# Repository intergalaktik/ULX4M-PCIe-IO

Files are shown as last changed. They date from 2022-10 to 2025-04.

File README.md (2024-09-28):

# ULX4M-PCIe-IO
NLnet funded PCIe board that can hold ULX4M-LD 

## PCIexpress-KiCad templates
PCI Express™ libraries and templates for KiCad
Made using guidelines from PCI Express™ Card Electromechanical Specification Rev. 1.1

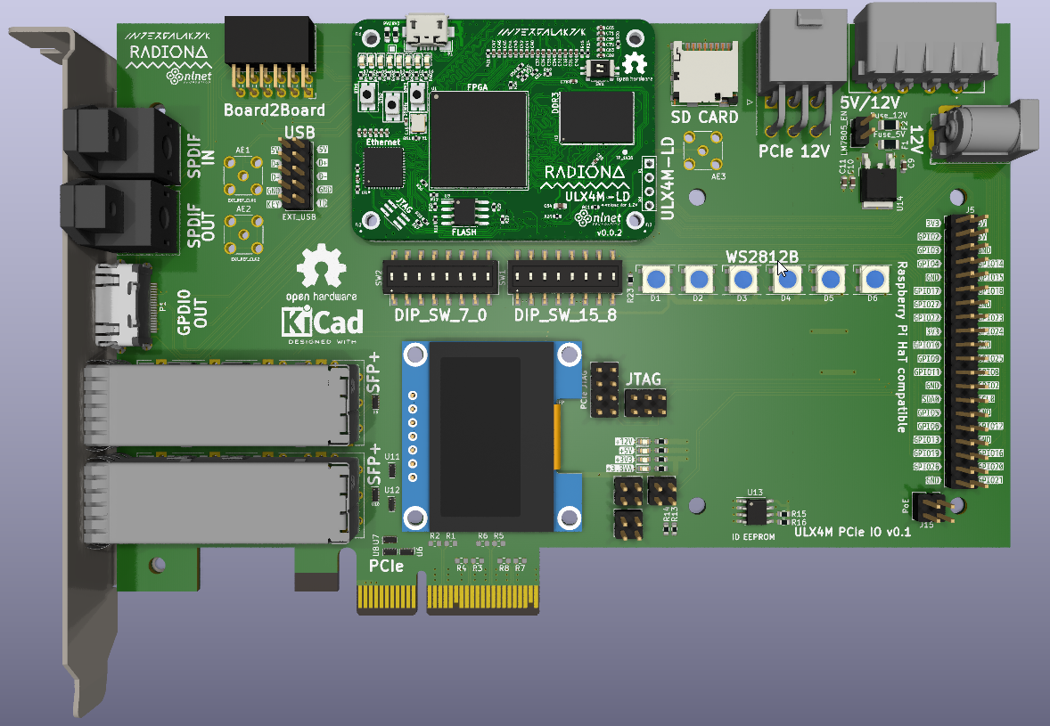
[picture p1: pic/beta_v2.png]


### Contents
**Template used:**
* x4 cards: full size, half length, low profile

**FPGA reference boards:**

* https://github.com/gatecat/TrellisBoard
* https://github.com/enjoy-digital/litex-acorn-baseboard

**Symbols:**
* x4
* Bracket

**Footprints:**
* x4 with multiple card outlines
* Full height bracket (with 3D model)

## Comfirmed working

- [x] 12V
- [x] 5V
- [x] 3.3V
- [x] DVI
- [x] WS2812 diodes
- [x] FTDI ove HAT

## Partially working

- [ ] PCIe loopback is working if TX/RX is bricked on boad edge, but not with PCIe externsion on CM4 IO board

## Not tested

- [ ] GPIOs
- [ ] SPDIFs
- [ ] SFPs
- [ ] PCIe comm to PC

# Not working

- [ ] OLED - pins are not connected on ULX4M
- [ ] 1x / 4x PCIe selection - it is not connected

### License
This documentation describes Open Hardware and is licensed under the CERN OHL v.1.2.

You may redistribute and modify this documentation under the terms of the CERN OHL v.1.2. (http://ohwr.org/cernohl). This documentation is distributed WITHOUT ANY EXPRESS OR IMPLIED WARRANTY, INCLUDING OF MERCHANTABILITY, SATISFACTORY QUALITY AND FITNESS FOR A PARTICULAR PURPOSE. Please see the CERN OHL v.1.2 for applicable conditions.

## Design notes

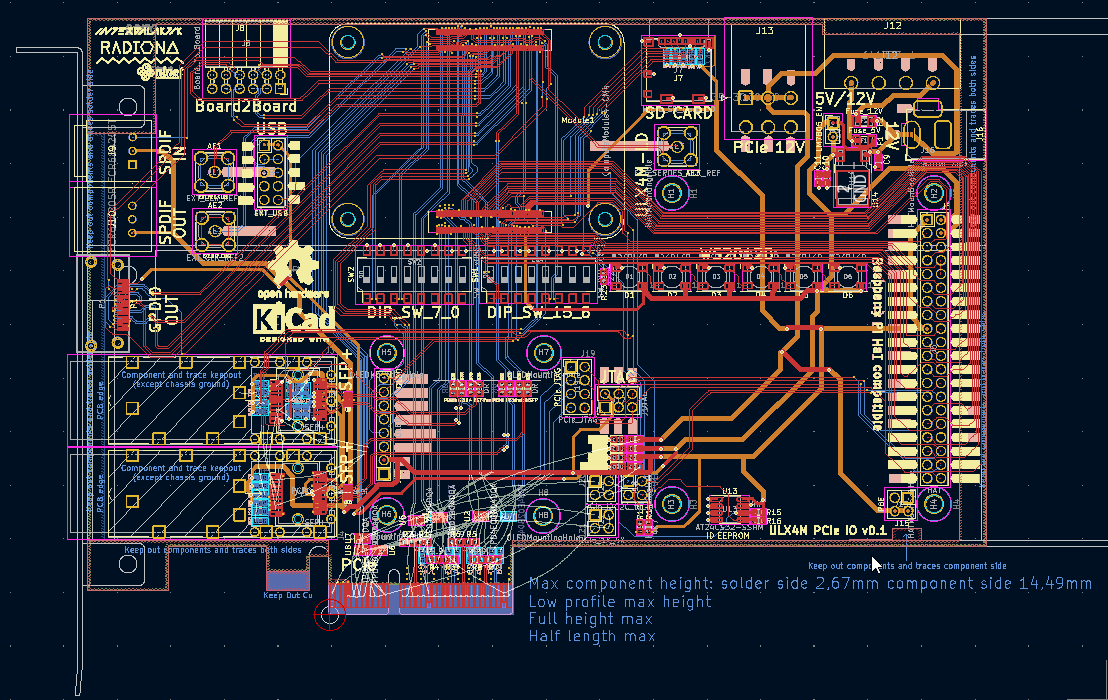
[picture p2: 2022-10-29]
pic/routing_status.png

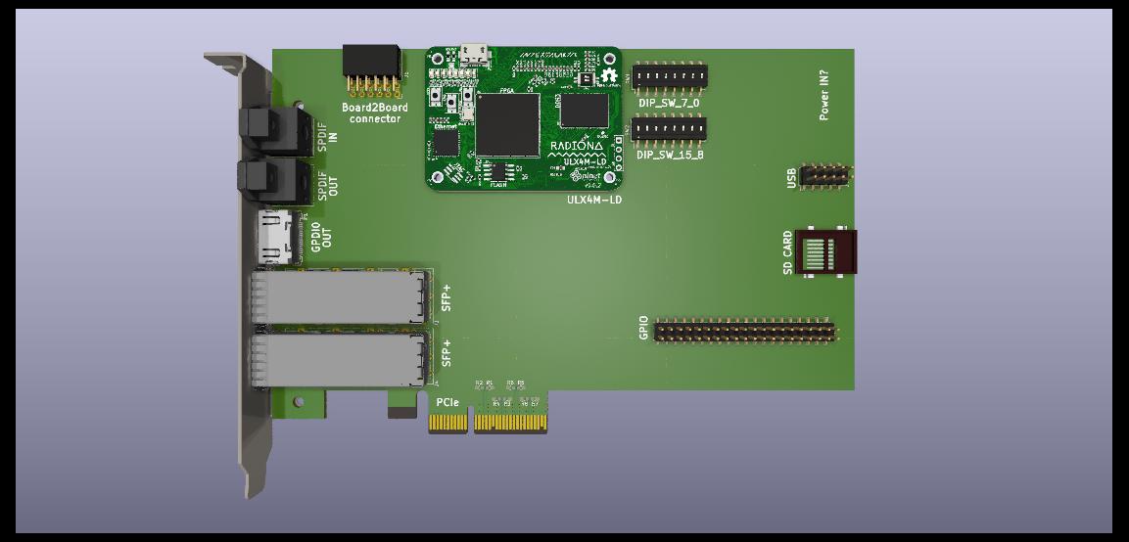
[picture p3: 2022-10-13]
pic/example.jpg

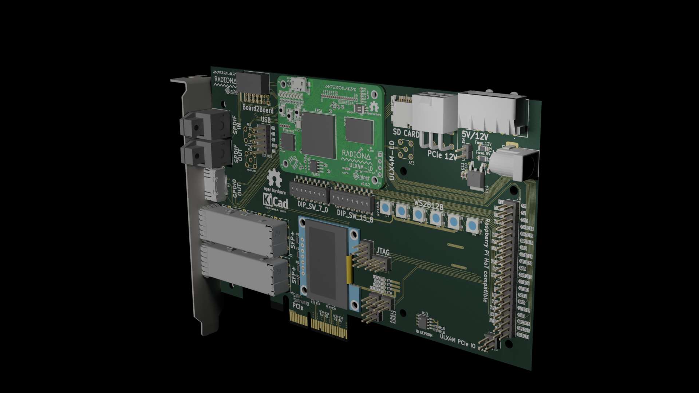
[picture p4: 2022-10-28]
3D/ULX4M-PCIE-IO.png

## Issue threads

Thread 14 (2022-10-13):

Adding few buttons

goran-mahovlic, 2022-10-13:

goran-mahovlic, 2022-10-24:
We have buttons on ULX4M, also all current pins are. When inside case buttons are useless...

Closed 2022-10-24.

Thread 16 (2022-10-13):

Trelis board has programable clock, and MUX for clk switching

goran-mahovlic, 2022-10-13:

goran-mahovlic, 2022-10-24:
Instead of MUX we will have two options, we can have 4X PCIe card without SPFs or 1X PCIe with 2 SFPs. It depends on placed resistors and on jumpers...

Closed 2022-10-24.

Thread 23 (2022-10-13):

GPDI wrong connector

goran-mahovlic, 2022-10-13:

goran-mahovlic, 2022-10-20:
https://github.com/intergalaktik/ULX4M-PCIe-IO/commit/fee51f18e15e3f0242d54034343057f6b9219a08

Closed 2022-10-20.

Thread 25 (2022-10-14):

Adding LEDs that will show all powersupplys

goran-mahovlic, 2022-10-14:

goran-mahovlic, 2022-10-20:
https://github.com/intergalaktik/ULX4M-PCIe-IO/commit/fee51f18e15e3f0242d54034343057f6b9219a08

Closed 2022-10-20.

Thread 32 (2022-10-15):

SYZYGY

goran-mahovlic, 2022-10-15:
Fast (>20Ms/s) multichannel (simultaneous sampling) ADC/DAC.
SYZYGY connectors for additional add-ons
SATA?
RAM slot?

(Doing all above via SYZYGY would be good and allow inter-op with [#Butterstick](https://twitter.com/hashtag/Butterstick?src=hashtag_click))

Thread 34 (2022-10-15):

emc2301

goran-mahovlic, 2022-10-15:
[@mminar7](https://twitter.com/mminar7)

I made project with fan management with emc2301 i2c chip. It could be added for managing 5 fan with emc2301-5. I build python3 driver for emc2301, I could help with adding it.

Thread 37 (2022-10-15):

Leds on bracket

goran-mahovlic, 2022-10-15:
Some LEDs on the... Whatchacallit, the metal bracket thingie, next to the SFP modules and other connectors.

goran-mahovlic, 2022-10-15:
may be better to add just connector and use extra bracket with LEDs

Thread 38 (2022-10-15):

USB on bracket

goran-mahovlic, 2022-10-15:
https://www.microconnectors.com/usb-2-0-2-ports-pc-expansion-slot-bracket-motherboard-high-speed-type-a-female-x-2-to-mpc-5-5-pin-x-2-for-atx-external-cover-case-mai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

Closed 2022-10-24.

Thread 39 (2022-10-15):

Leon

goran-mahovlic, 2022-10-15:
I would remove the 0.96" OLED and instead maybe rearrange the right part of the card so it's shorter. The OLED seems a bit unnecessary since you have pcie and sfp, thus you can setup state monitoring inside some software on the host PC or over the network.

If there won't be additional circuitry, I would place the SD card slot near the fpga oriented upwards(instead of the DIP switches, they would go in place of the OLED), but make it a push-latching mechanism slot so the microSD card can be easily removed whilst the pcie card is installed.

Also, I would place the GPIO header on the right edge of the card, not the straight one, but the 90° angled one so the ribbon cable could be easily plugged and routed further through the system and not interfere with stacking another card on top.

If you plan to add more connectivity and add ADCs and DACs as others have suggested, I would also consider making the back-plate a dual-slotted one so all the connectors and indicators would fit.

goran-mahovlic, 2022-10-20:
OLED, SDCARD and GPIO moved - ADC is addressed in https://github.com/intergalaktik/ULX4M-PCIe-IO/issues/20

Closed 2022-10-20.

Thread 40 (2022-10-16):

Miroslav

goran-mahovlic, 2022-10-16:
I'd say it depends a lot on the target application/use.

If you want to use it as a standalone board as well as a PCI Express card;
- having an OLED is fine, but inside the case it is likely unusable (if it's mounted on a tower case it will point downwards).
- Also, Power In, if not used from a PC enclosure, should not be constrained to PCIe only, I would put a barrel connector for power input.
- Finally, there should be a separate USB connector for the onboard JTAG programming (meaning full onboard FTDI chip and micro-B or type C connector)

The form factor is very similar to the Lattice Versa board, so you might take a few design hints from there.

Also, SFPs are fine, but are added cost if anyone wants simply to connect to Ethernet. Having also a PHY and RJ45 with Ethernet would help people onboard faster.

Is this a HDMI connector for the ext. GPIO pins? I find this a rather strange choice so I wonder the rationale behind it.

goran-mahovlic, 2022-10-20:
>> having an OLED is fine, but inside the case it is likely unusable (if it's mounted on a tower case it will point downwards).

Holders added
>> Also, Power In, if not used from a PC enclosure, should not be constrained to PCIe only, I would put a barrel connector for power input.

done

>> Finally, there should be a separate USB connector for the onboard JTAG programming (meaning full onboard FTDI chip and micro-B or type C connector)

Added JTAG connector - FTDI should go on HAT >> opening issue on that one

>> Also, SFPs are fine, but are added cost if anyone wants simply to connect to Ethernet. Having also a PHY and RJ45 with Ethernet would help people onboard faster.

Chip shortage is bad and we cannot be sure that we will get 1Gb chip. Also if chip is used one SerDes pair is lost. So I wil skip that for now.

Closed 2022-10-20.

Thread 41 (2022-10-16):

Chili. CHIPS ba

goran-mahovlic, 2022-10-16:
1) Have you considered adding a high-speed ADC, to so open the door to PC-hosted apps of https://redpitaya.com/ kind?
2) How about a shorter form-factor, one that can fit in the micro or mini cases?
3) Interfaces for Industrial Control components /*step motors, sensors, CNC machines in general*/ may also be of interest.
http://store.mesanet.com/index.php?route=product/category&path=83_85

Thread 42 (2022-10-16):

DC/DC 12V to 5V is missing

goran-mahovlic, 2022-10-16:

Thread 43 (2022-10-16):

12V power to HAT - probably possible over POE connector

goran-mahovlic, 2022-10-16:

goran-mahovlic, 2022-10-20:
https://github.com/intergalaktik/ULX4M-PCIe-IO/commit/fee51f18e15e3f0242d54034343057f6b9219a08

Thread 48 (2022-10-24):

Latest kicad is crashing if I try to route any signal

goran-mahovlic, 2022-10-24:

goran-mahovlic, 2022-10-26:
Fixed in latest nighty

Closed 2022-10-26.

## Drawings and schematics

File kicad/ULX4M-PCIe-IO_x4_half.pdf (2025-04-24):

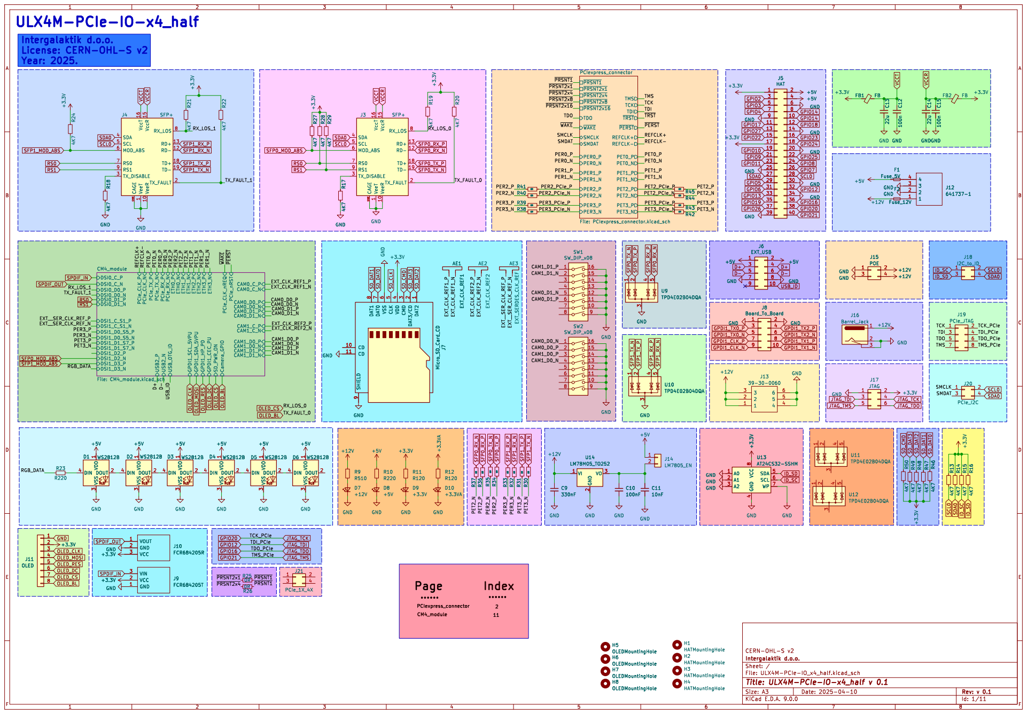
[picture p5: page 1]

1 VccR 15 VeeR 10 RX_LOS 8 RD+ 13 RD- 12 TD+ 18 TD- 19 TX_FAULT 2

4 SDA 5 SCL 6 WP 7 +3.3V GND

3 DOUT 2 D1 WS2812B R23 R220 +5V H2 HATMountingHole H3 HATMountingHole H1 HATMountingHole H7 OLEDMountingHole

4 SDA 5 SCL 6 WP 7 U13 AT24CS32-SSHM

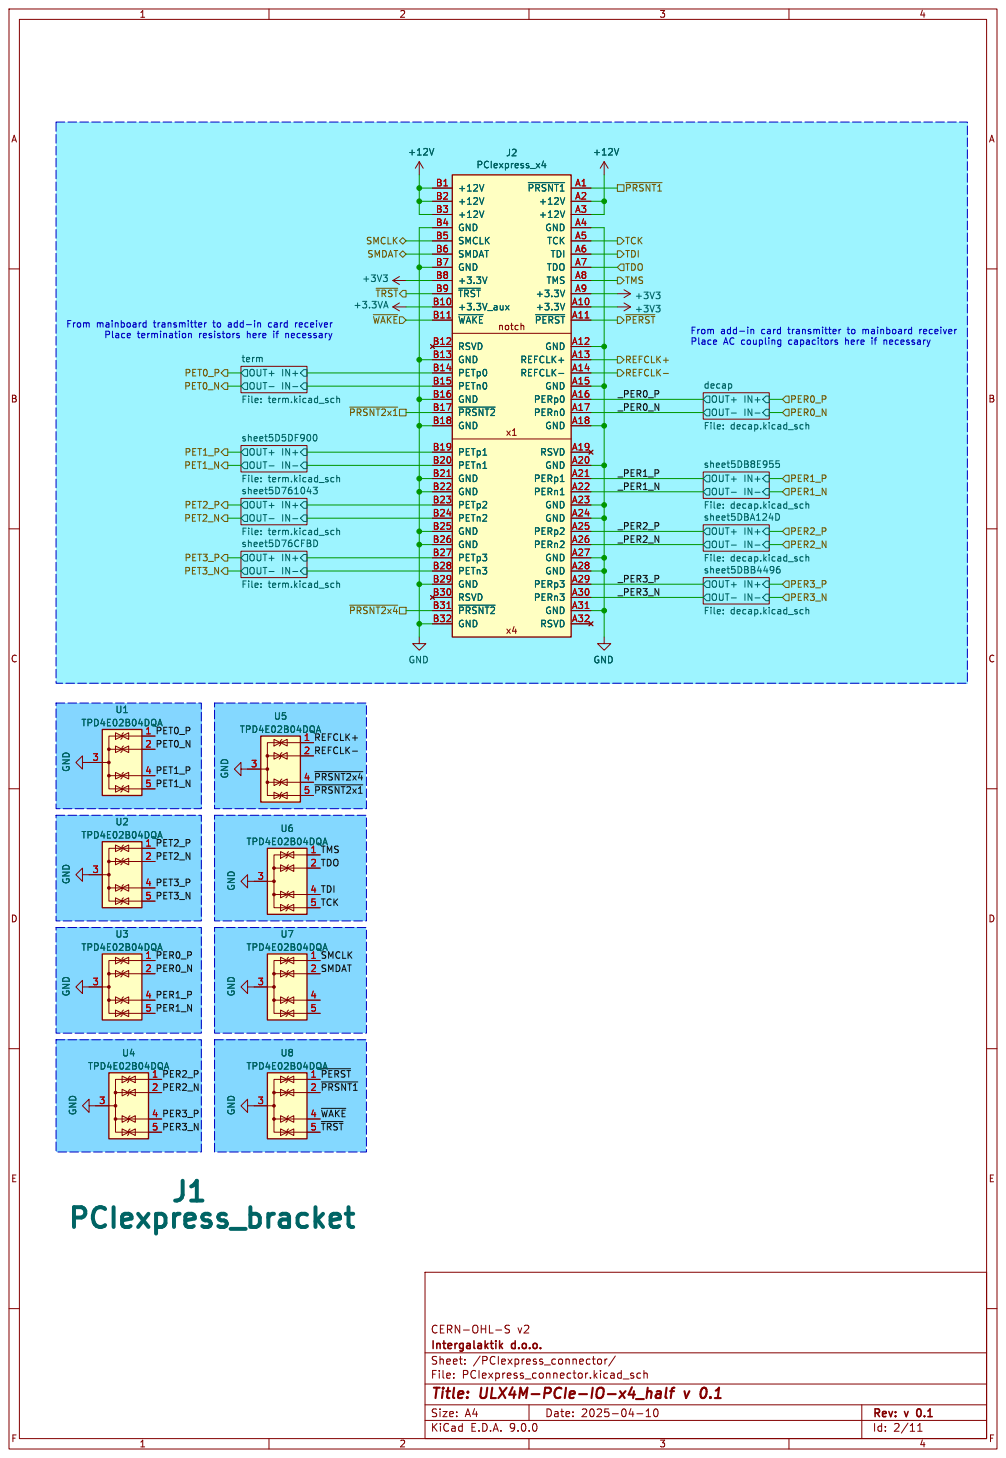
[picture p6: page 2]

IN- OUT+ OUT- sheet5D5DF900 File: term.kicad_sch

IN- OUT+ OUT- sheet5D761043 File: term.kicad_sch

OUT+ IN+ OUT- IN- sheet5DBB4496 File: decap.kicad_sch OUT+ IN+ OUT- IN- sheet5DBA124D

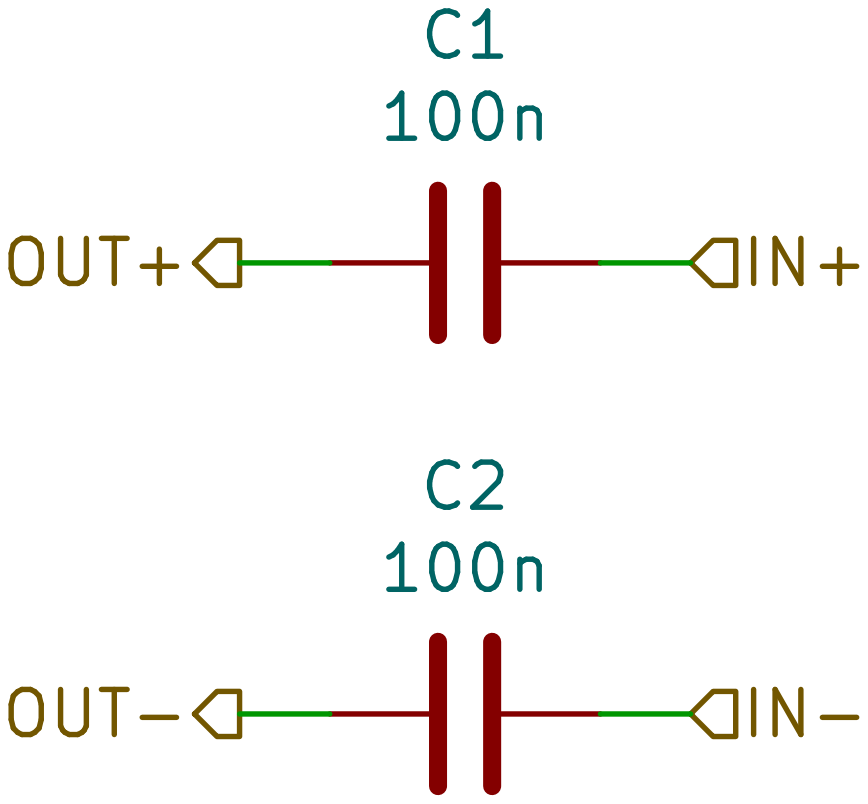
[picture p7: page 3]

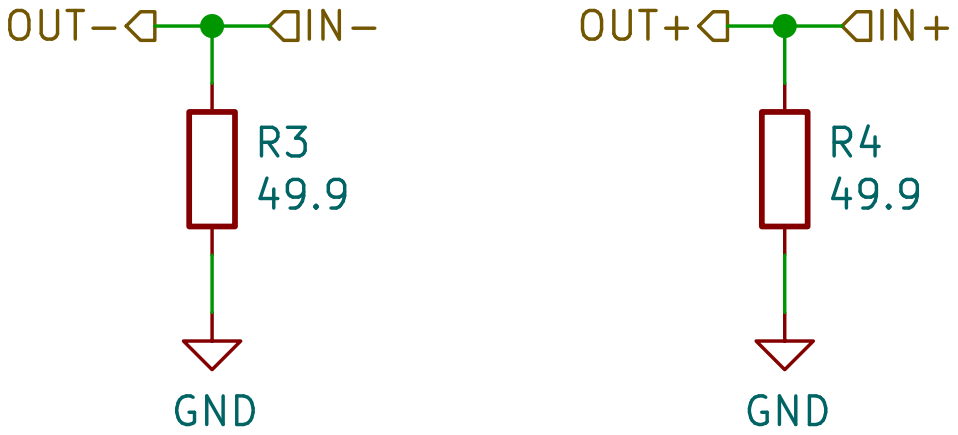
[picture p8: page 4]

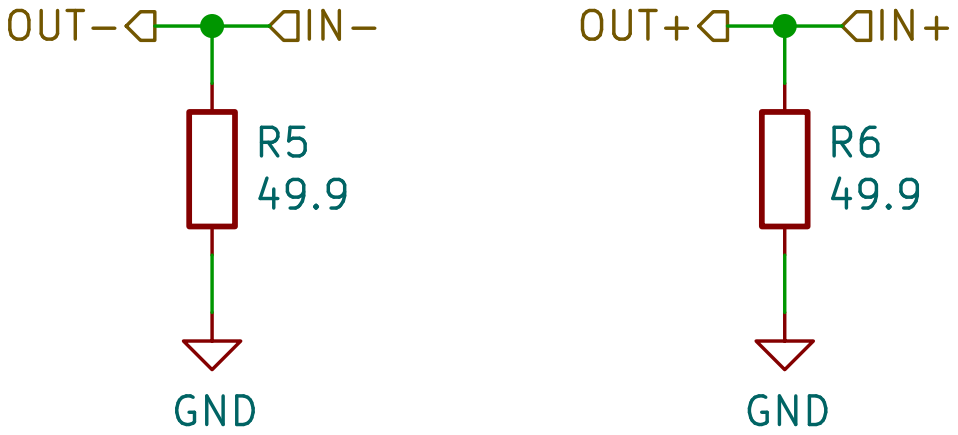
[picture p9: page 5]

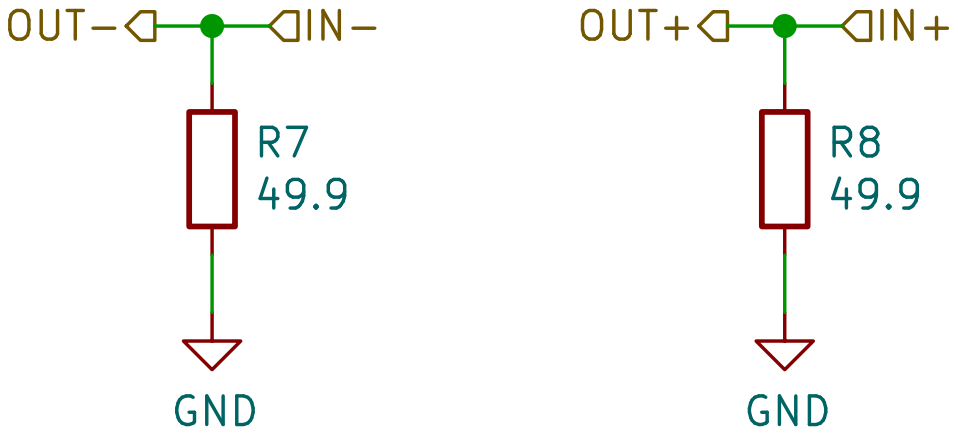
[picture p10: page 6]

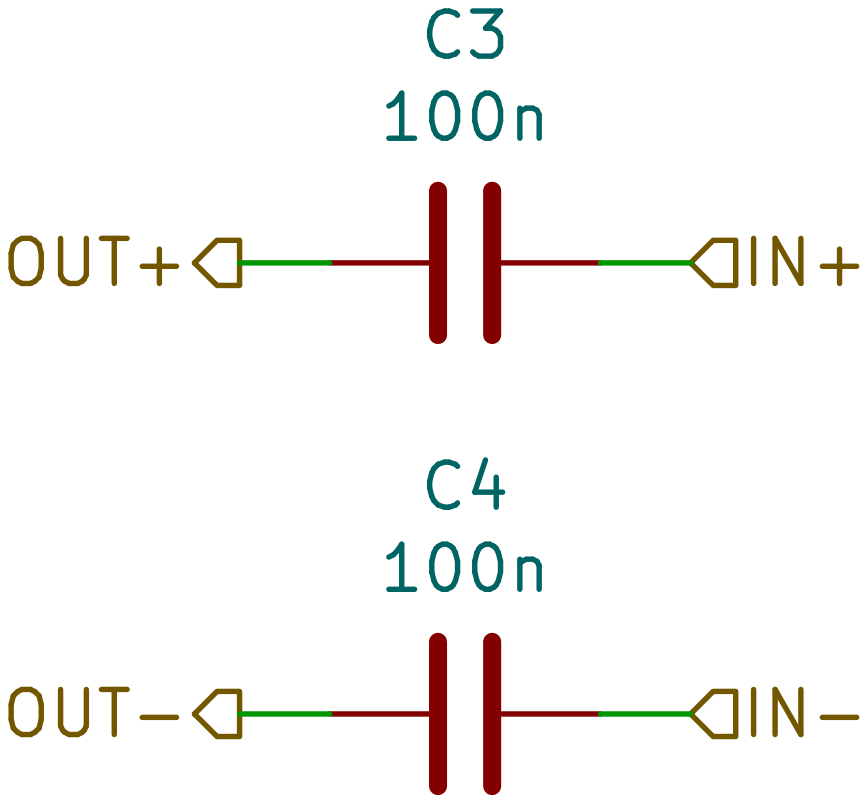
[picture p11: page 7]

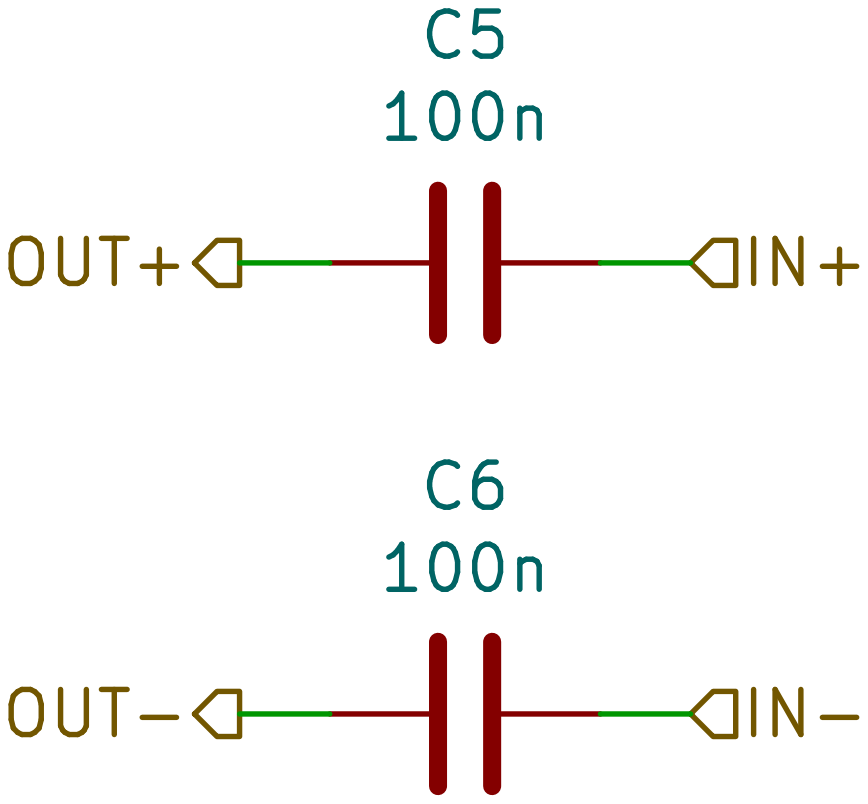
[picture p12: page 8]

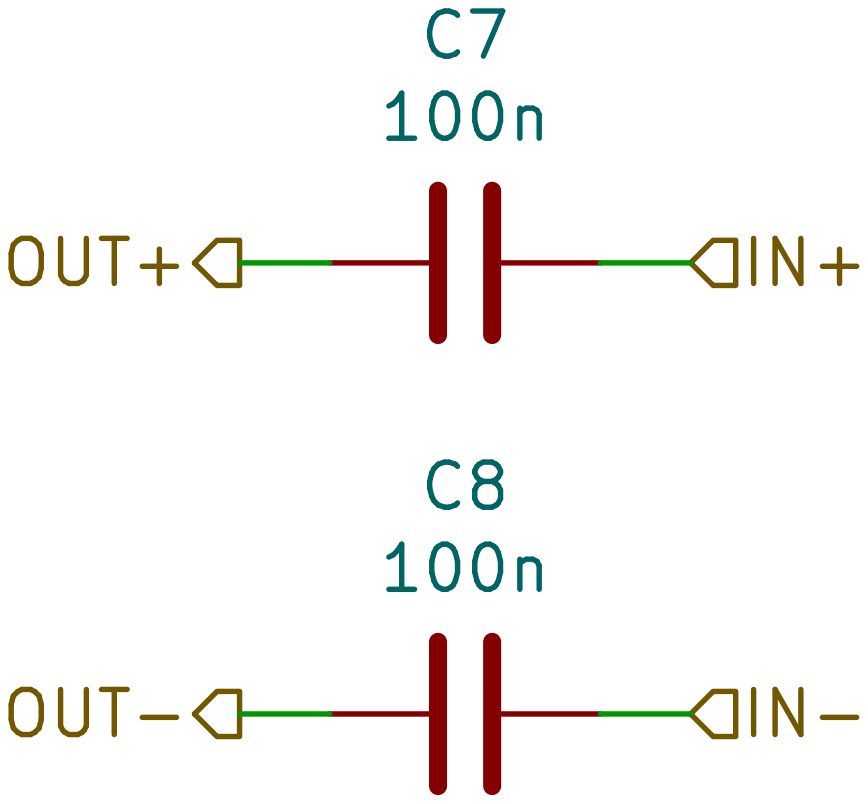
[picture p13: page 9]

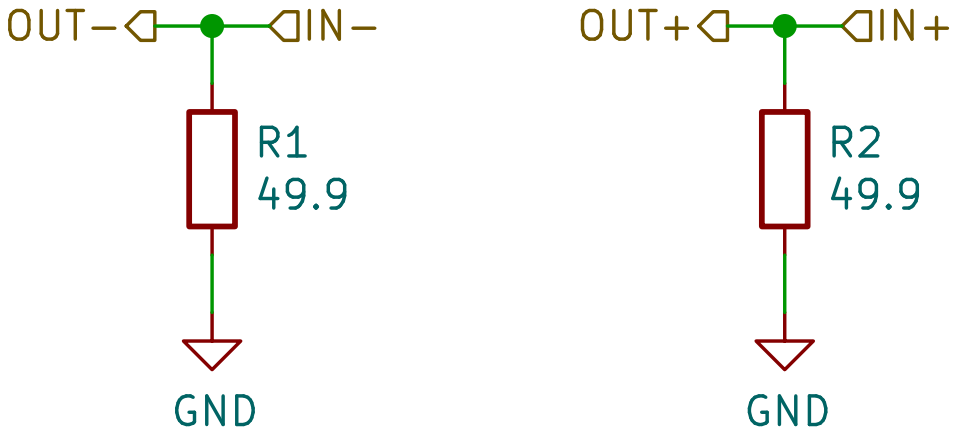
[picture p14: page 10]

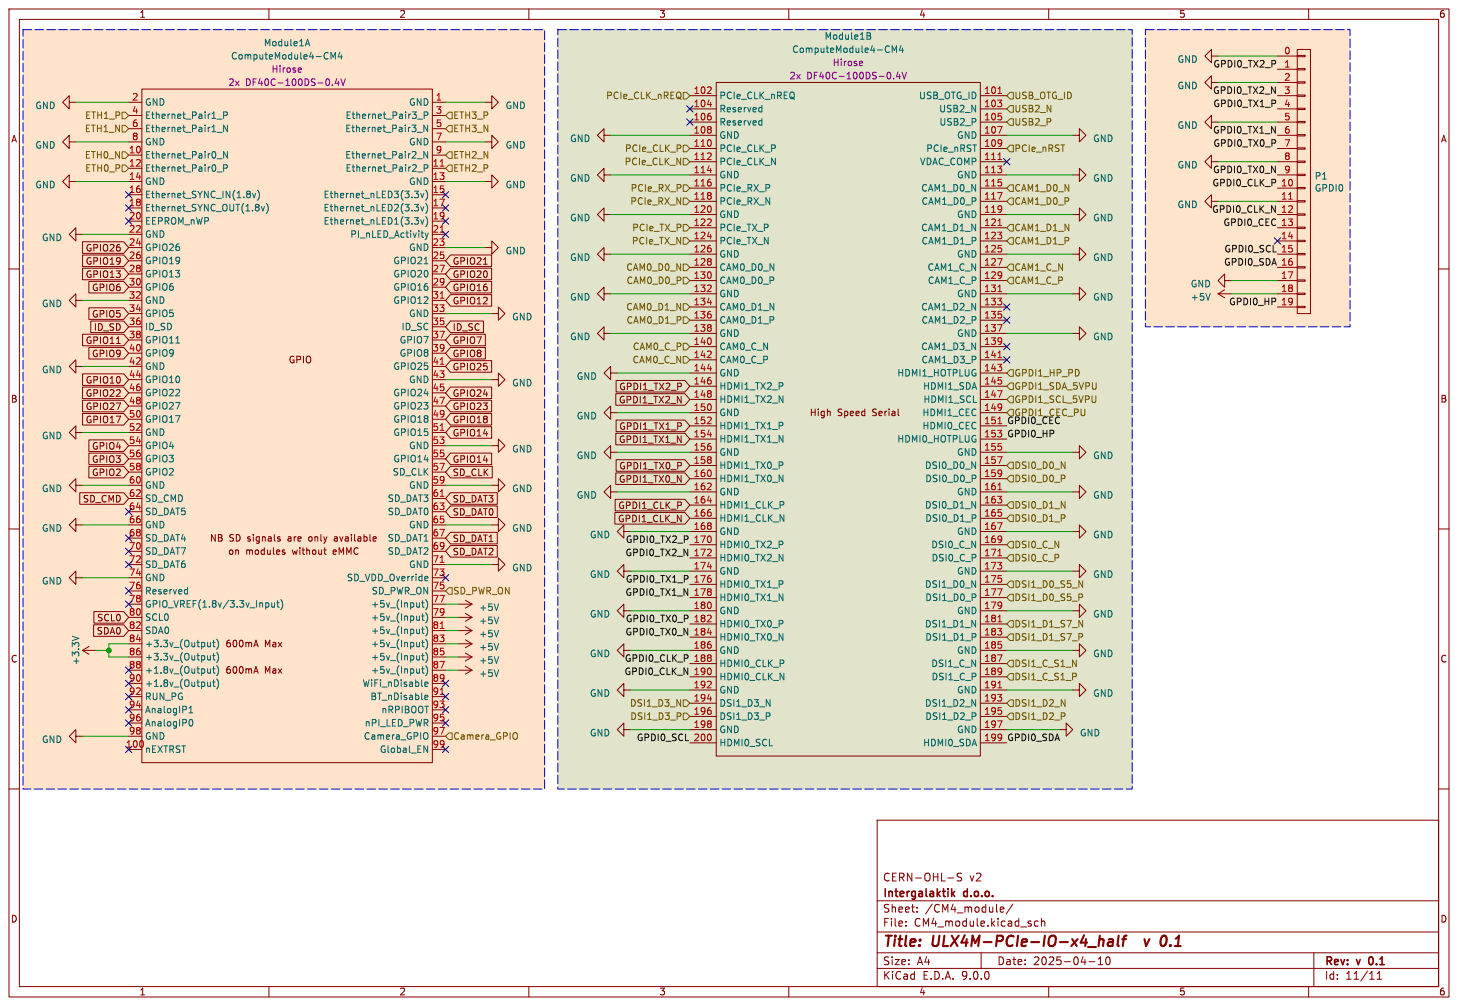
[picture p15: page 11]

Module1B ComputeModule4-CM4 Hirose
High Speed Serial PCIe_CLK_nREQ 102 Reserved 104 Reserved 106 GND 108 PCIe_CLK_P 110 PCIe_CLK_N 112 GND 114 PCIe_RX_P 116 PCIe_RX_N 118 GND 120 PCIe_TX_P 122 PCIe_TX_N 124 GND 126 CAM0_D0_N 128 CAM0_D0_P 130 GND 132 CAM0_D1_N 134 CAM0_D1_P 136 GND 138 CAM0_C_N 140 CAM0_C_P 142 GND 144 HDMI1_TX2_P 146 HDMI1_TX2_N 148 GND 150 HDMI1_TX1_P 152 HDMI1_TX1_N 154 GND 156 HDMI1_TX0_P 158 HDMI1_TX0_N 160 GND 162 HDMI1_CLK_P 164 HDMI1_CLK_N 166 GND 168 HDMI0_TX2_P 170 HDMI0_TX2_N 172 GND 174 HDMI0_TX1_P 176 HDMI0_TX1_N 178 GND 180 HDMI0_TX0_P 182 HDMI0_TX0_N 184 GND 186 HDMI0_CLK_P 188 HDMI0_CLK_N 190 GND 192 DSI1_D3_N 194 DSI1_D3_P 196 GND 198 HDMI0_SCL 200
ETH2_N
ETH2_P

2x DF40C-100DS-0.4V CAM0_C_N
USB_OTG_ID 101 USB2_N 103 USB2_P 105 GND 107 PCIe_nRST 109 VDAC_COMP 111 GND 113 CAM1_D0_N 115 CAM1_D0_P 117 GND 119 CAM1_D1_N 121 CAM1_D1_P 123 GND 125 CAM1_C_N 127 CAM1_C_P 129 GND 131 CAM1_D2_N 133 CAM1_D2_P 135 GND 137 CAM1_D3_N 139 CAM1_D3_P 141 HDMI1_HOTPLUG 143 HDMI1_SDA 145 HDMI1_SCL 147 HDMI1_CEC 149 HDMI0_CEC 151 HDMI0_HOTPLUG 153 GND 155 DSI0_D0_N 157 DSI0_D0_P 159 GND 161 DSI0_D1_N 163 DSI0_D1_P 165 GND 167 DSI0_C_N 169 DSI0_C_P 171 GND 173 DSI1_D0_N 175 DSI1_D0_P 177 GND 179 DSI1_D1_N 181 DSI1_D1_P 183 GND 185 DSI1_C_N 187 DSI1_C_P 189 GND 191 DSI1_D2_N 193 DSI1_D2_P 195 GND 197 HDMI0_SDA 199
PCIe_nRST DSI1_C_S1_P

on modules without eMMC GPIO

600mA Max 600mA Max NB SD signals are only available

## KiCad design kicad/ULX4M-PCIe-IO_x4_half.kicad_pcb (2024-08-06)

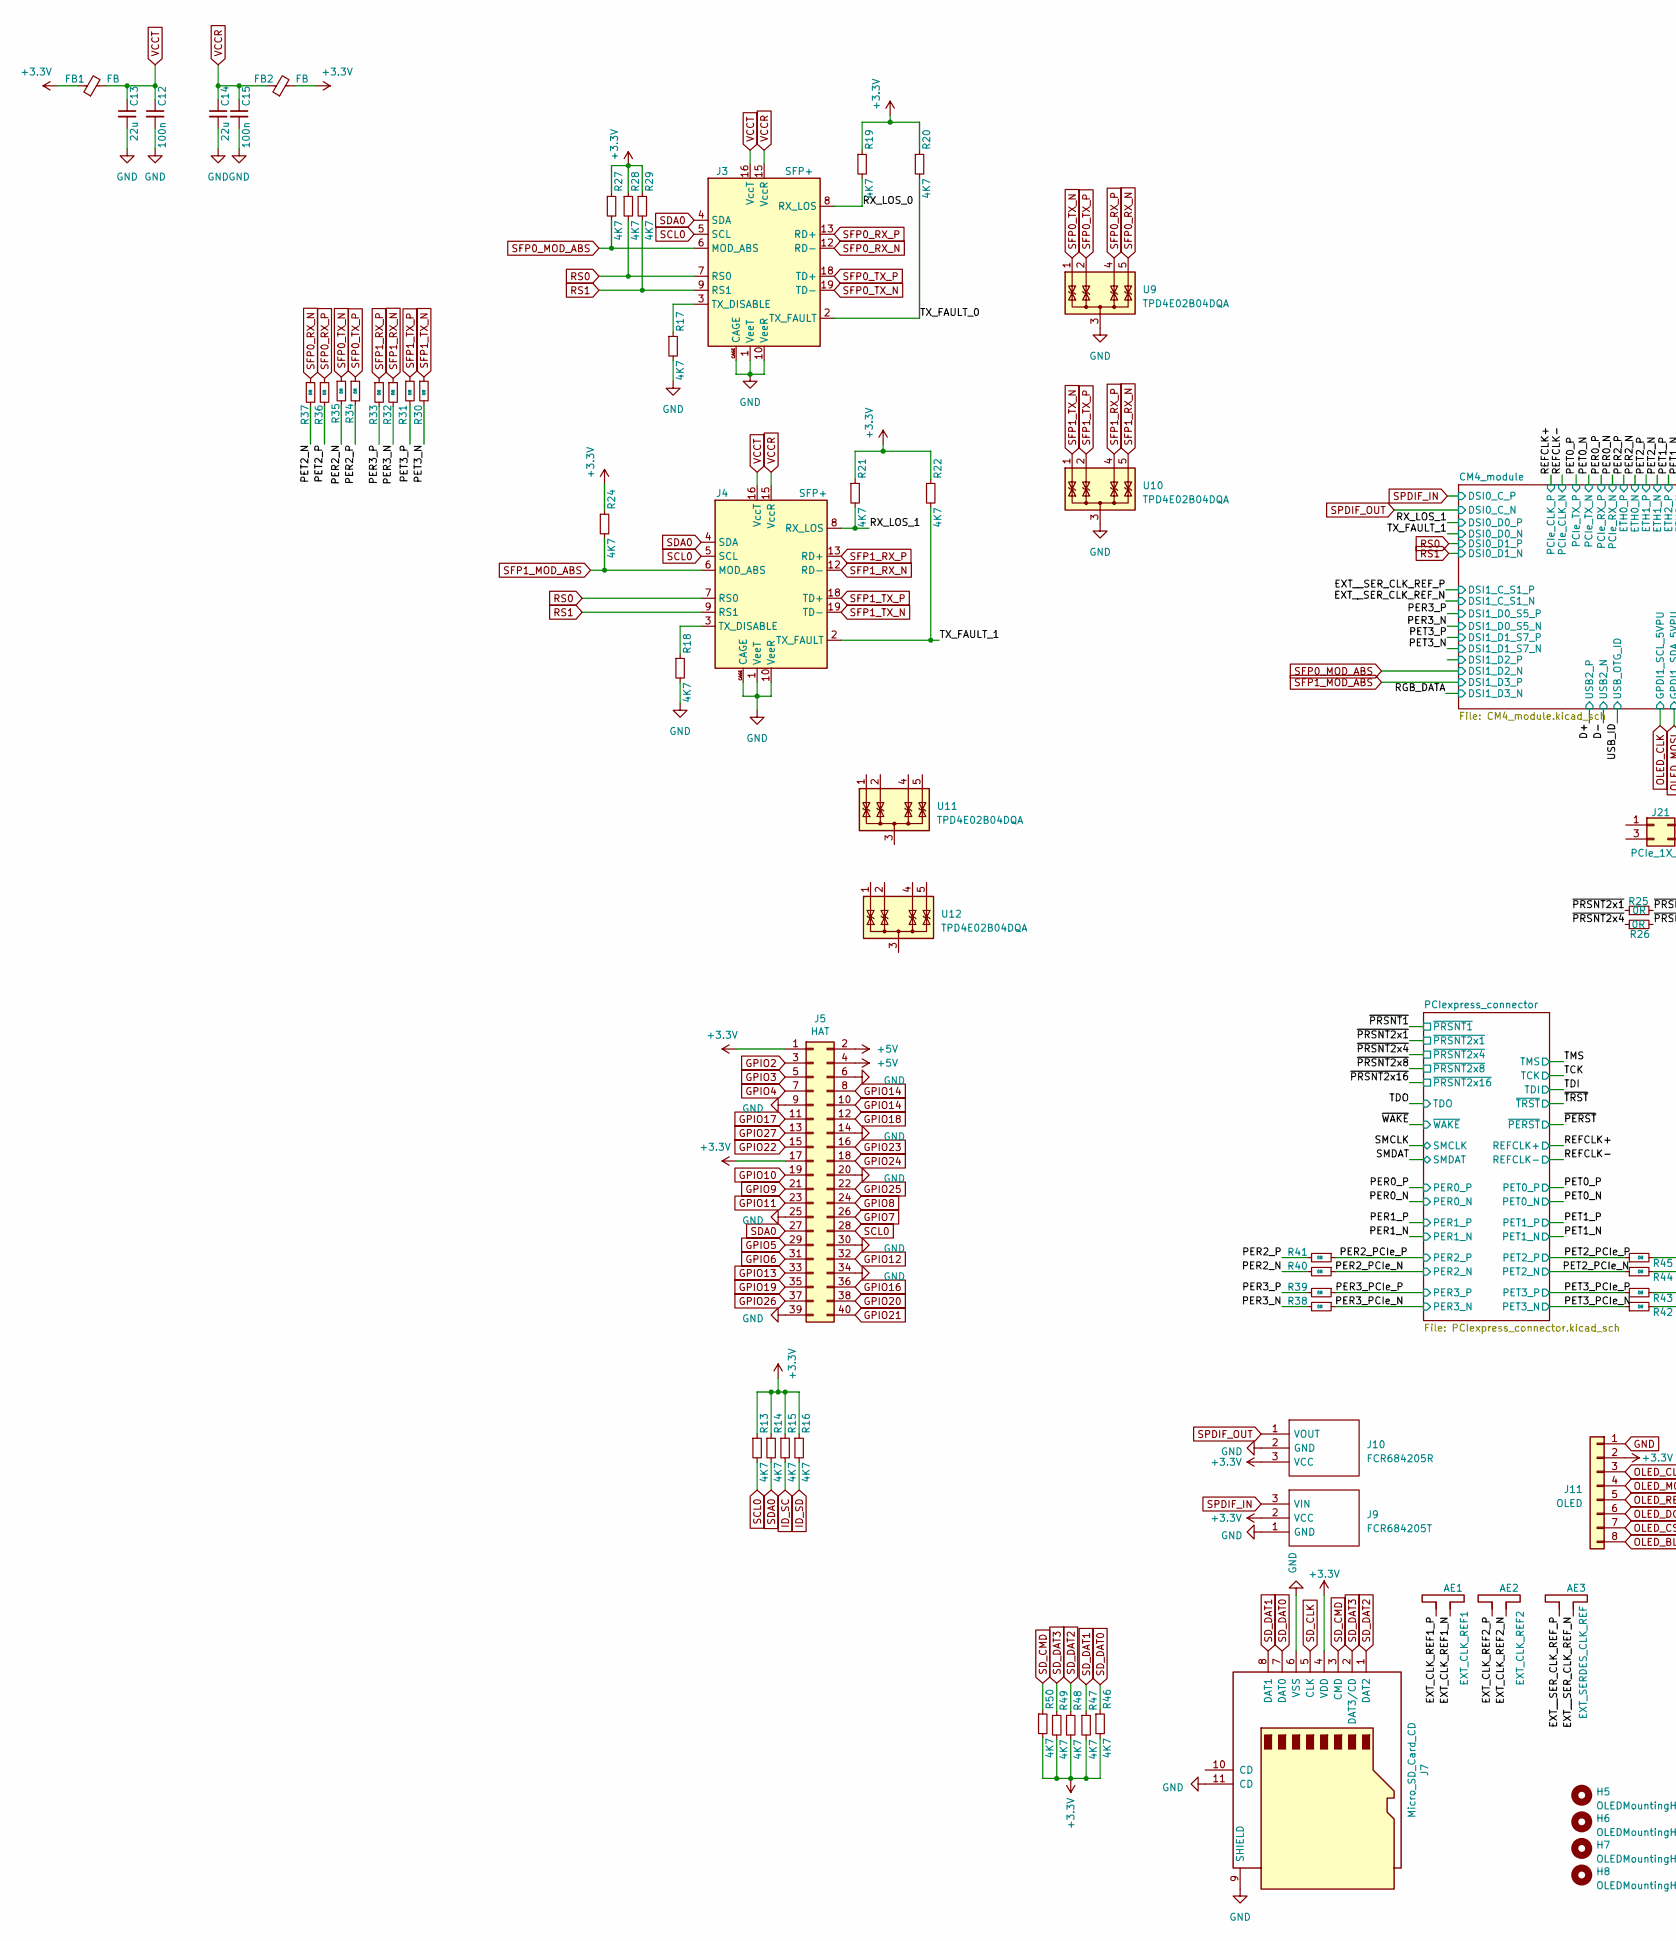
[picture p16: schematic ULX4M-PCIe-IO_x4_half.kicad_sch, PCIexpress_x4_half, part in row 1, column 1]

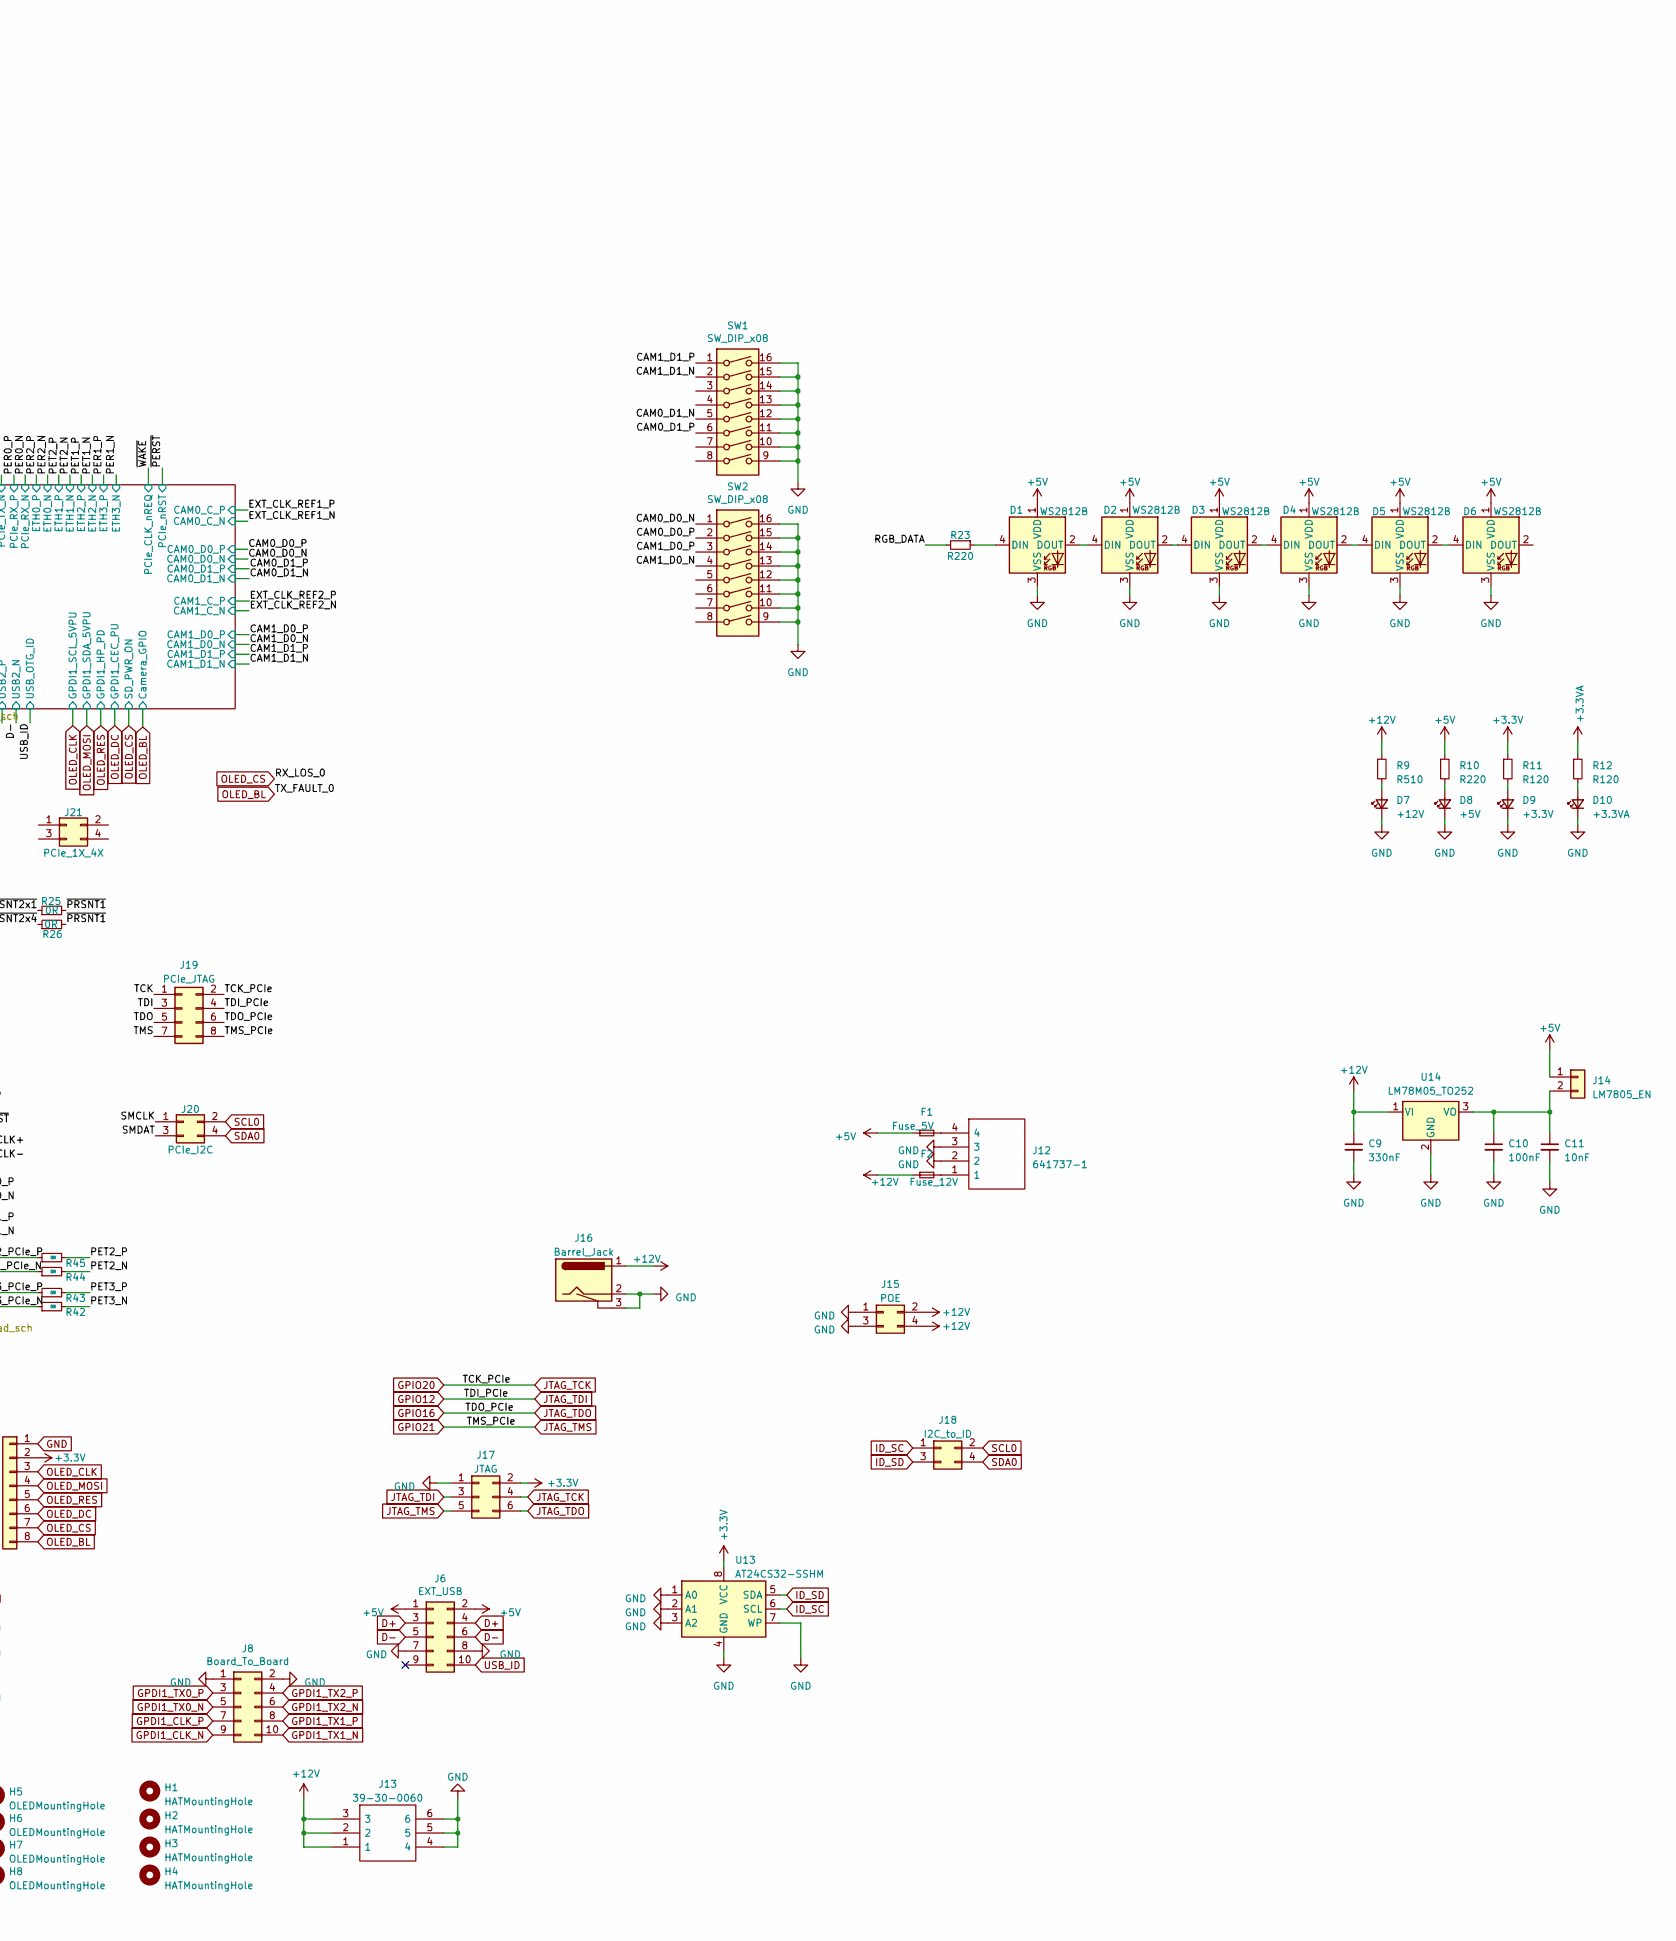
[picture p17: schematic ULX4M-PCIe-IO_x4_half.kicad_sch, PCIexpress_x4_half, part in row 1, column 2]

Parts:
AE1: EXT_CLK_REF1; SMA_Amphenol_132291-12_Vertical
AE2: EXT_CLK_REF2; SMA_Amphenol_132291-12_Vertical
AE3: EXT_SERDES_CLK_REF; SMA_Amphenol_132291-12_Vertical
C9: 330nF; C_0603_1608Metric
C10: 100nF; C_0603_1608Metric
C11: 10nF; C_0603_1608Metric
C12, C15: 100n; C_0603_1608Metric
C13, C14: 22u; C_0603_1608Metric
D1, D2, D3, D4, D5, D6: WS2812B; LED_WS2812B_PLCC4_5.0x5.0mm_P3.2mm
D7: +12V; LED_0603_1608Metric
D8: +5V; LED_0603_1608Metric
D9: +3.3V; LED_0603_1608Metric
D10: +3.3VA; LED_0603_1608Metric
F1: Fuse_5V; Fuse_1206_3216Metric
F2: Fuse_12V; Fuse_1206_3216Metric
FB1, FB2: FB; L_0603_1608Metric
H1, H2, H3, H4: HATMountingHole; MountingHole_3.2mm_M3
H5, H6, H7, H8: OLEDMountingHole; MountingHole_3.2mm_M3
J3, J4: SFP+; Connector_SFP_and_Cage
J5: HAT; PinHeader_2x20_P2.54mm_Vertical
J6: EXT_USB; PinHeader_2x05_P2.54mm_Vertical
J7: Micro_SD_Card_CD; microSD_HC_Molex_104031-0811
J8: Board_To_Board; PinSocket_2x06_P2.54mm_Horizontal
J9: FCR684205T; Manufacturer_Part_Number FCR684205T
J10: FCR684205R; Manufacturer_Part_Number FCR684205R
J11: OLED; PinHeader_1x08_P2.54mm_Vertical
J12: 641737-1; Mouser Part Number 571-6417371
J13: 39-30-0060; 39-30-Y060; Mouser Part Number 538-39-30-0060
J14: LM7805_EN; PinHeader_1x02_P2.54mm_Vertical
J15: POE; PinHeader_2x02_P2.54mm_Vertical
J16: Barrel_Jack; BarrelJack_Horizontal
J17: JTAG; PinHeader_2x03_P2.54mm_Vertical
J18: I2C_to_ID; PinHeader_2x02_P2.54mm_Vertical
J19: PCIe_JTAG; PinHeader_2x04_P2.54mm_Vertical
J20: PCIe_I2C; PinHeader_2x02_P2.54mm_Vertical
J21: PCIe_1X_4X; PinHeader_2x02_P2.54mm_Vertical
R9: R510; R_0603_1608Metric
R10, R23: R220; R_0603_1608Metric
R11, R12: R120; R_0603_1608Metric
R13, R14, R15, R16, R17, R18, R19, R20, R21, R22, R24, R27, R28, R29, R46, R47, R48, R49, R50: 4K7; R_0603_1608Metric
R25, R26: 0R
R30, R31, R32, R33, R34, R35, R36, R37, R38, R39, R40, R41, R42, R43, R44, R45: 0R; R_0603_1608Metric
SW1, SW2: SW_DIP_x08; SW_DIP_SPSTx08_Slide_Omron_A6S-810x_W8.9mm_P2.54mm
U9, U10, U11, U12: TPD4E02B04DQA; USON-10_2.5x1.0mm_P0.5mm
U13: AT24CS32-SSHM; SOIC-8_3.9x4.9mm_P1.27mm
U14: LM78M05_TO252; TO-252-2

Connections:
+3.3V: FB1.1, FB2.2, J5.1, J5.17, J7.4 (VDD), J9.2 (VCC), J10.3 (VCC), J11.2, J17.2, R11.1, R13.1, R14.1, R15.1, R16.1, R19.1, R20.1, R21.1, R22.1, R24.1, R27.1, R28.1, R29.1, R46.2, R47.2, R48.2, R49.2, R50.2, U13.8 (VCC); also elsewhere on the board
+3.3VA: R12.1; also elsewhere on the board
+5V: D1.1 (VDD), D2.1 (VDD), D3.1 (VDD), D4.1 (VDD), D5.1 (VDD), D6.1 (VDD), F1.1, J5.2, J5.4, J6.1, J6.2, J14.1, R10.1; also elsewhere on the board
+12V: C9.1, F2.1, J13.1, J13.2, J13.3, J15.2, J15.4, J16.1, R9.1, U14.1 (VI); also elsewhere on the board
/CAM0_D0_N: SW2.1; also elsewhere on the board
/CAM0_D0_P: SW2.2; also elsewhere on the board
/CAM0_D1_N: SW1.5; also elsewhere on the board
/CAM0_D1_P: SW1.6; also elsewhere on the board
/CAM1_D0_N: SW2.4; also elsewhere on the board
/CAM1_D0_P: SW2.3; also elsewhere on the board
/CAM1_D1_N: SW1.2; also elsewhere on the board
/CAM1_D1_P: SW1.1; also elsewhere on the board
/EXT_CLK_REF1_N: AE1.2; also elsewhere on the board
/EXT_CLK_REF1_P: AE1.1; also elsewhere on the board
/EXT_CLK_REF2_N: AE2.2; also elsewhere on the board
/EXT_CLK_REF2_P: AE2.1; also elsewhere on the board
/EXT__SER_CLK_REF_N: AE3.2; also elsewhere on the board
/EXT__SER_CLK_REF_P: AE3.1; also elsewhere on the board
/PER2_N: R35.2, R40.2; also elsewhere on the board
/PER2_P: R34.2, R41.2; also elsewhere on the board
/PER2_PCIe_N: R40.1; also elsewhere on the board
/PER2_PCIe_P: R41.1; also elsewhere on the board
/PER3_N: R32.2, R38.2; also elsewhere on the board
/PER3_P: R33.2, R39.2; also elsewhere on the board
/PER3_PCIe_N: R38.1; also elsewhere on the board
/PER3_PCIe_P: R39.1; also elsewhere on the board
/PET2_N: R37.2, R44.2; also elsewhere on the board
/PET2_P: R36.2, R45.2; also elsewhere on the board
/PET2_PCIe_N: R44.1; also elsewhere on the board
/PET2_PCIe_P: R45.1; also elsewhere on the board
/PET3_N: R30.2, R42.2; also elsewhere on the board
/PET3_P: R31.2, R43.2; also elsewhere on the board
/PET3_PCIe_N: R42.1; also elsewhere on the board
/PET3_PCIe_P: R43.1; also elsewhere on the board
/RGB_DATA: R23.2; also elsewhere on the board
/RX_LOS_1: J4.8 (RX_LOS), R21.2; also elsewhere on the board
/SMCLK: J20.1; also elsewhere on the board
/SMDAT: J20.3; also elsewhere on the board
/TCK: J19.1; also elsewhere on the board
/TDI: J19.3; also elsewhere on the board
/TDO: J19.5; also elsewhere on the board
/TMS: J19.7; also elsewhere on the board
/TX_FAULT_1: J4.2 (TX_FAULT), R22.2; also elsewhere on the board
/~PRSNT1: J21.2, J21.4; also elsewhere on the board
/~PRSNT2x1: J21.1; also elsewhere on the board
/~PRSNT2x4: J21.3; also elsewhere on the board
D+: J6.3, J6.4; also elsewhere on the board
D-: J6.5, J6.6; also elsewhere on the board
GND: C9.2, C10.2, C11.2, C12.2, C13.2, C14.2, C15.2, D1.3 (VSS), D2.3 (VSS), D3.3 (VSS), D4.3 (VSS), D5.3 (VSS), D6.3 (VSS), D7.1 (K), D8.1 (K), D9.1 (K), D10.1 (K), J3.1 (VeeT), J3.10 (VeeR), J3.11 (VeeR), J3.14 (VeeR), J3.17 (VeeT), J3.20 (VeeT), J3.CAGE, J4.1 (VeeT), J4.10 (VeeR), J4.11 (VeeR), J4.14 (VeeR), J4.17 (VeeT), J4.20 (VeeT), J4.CAGE, J5.6, J5.9, J5.14, J5.20, J5.25, J5.30, J5.34, J5.39, J6.7, J6.8, J7.6 (VSS), J7.9 (SHIELD), J7.11 (CD), J8.1, J8.2, J9.1 (GND), J10.2 (GND), J11.1, J12.2, J12.3, J13.4, J13.5, J13.6, J15.1, J15.3, J16.2, J16.3, J17.1, R17.2, R18.2, SW1.9, SW1.10, SW1.11, SW1.12, SW1.13, SW1.14, SW1.15, SW1.16, SW2.9, SW2.10, SW2.11, SW2.12, SW2.13, SW2.14, SW2.15, SW2.16, U9.3 (G), U9.8 (G), U10.3 (G), U10.8 (G), U13.1 (A0), U13.2 (A1), U13.3 (A2), U13.4 (GND), U13.7 (WP), U14.2 (GND); also elsewhere on the board
GPDI1_CLK_N: J8.9; also elsewhere on the board
GPDI1_CLK_P: J8.7; also elsewhere on the board
GPDI1_TX0_N: J8.5; also elsewhere on the board
GPDI1_TX0_P: J8.3; also elsewhere on the board
GPDI1_TX1_N: J8.10; also elsewhere on the board
GPDI1_TX1_P: J8.8; also elsewhere on the board
GPDI1_TX2_N: J8.6; also elsewhere on the board
GPDI1_TX2_P: J8.4; also elsewhere on the board
GPIO2: J5.3; also elsewhere on the board
GPIO3: J5.5; also elsewhere on the board
GPIO4: J5.7; also elsewhere on the board
GPIO5: J5.29; also elsewhere on the board
GPIO6: J5.31; also elsewhere on the board
GPIO7: J5.26; also elsewhere on the board
GPIO8: J5.24; also elsewhere on the board
GPIO9: J5.21; also elsewhere on the board
GPIO10: J5.19; also elsewhere on the board
GPIO11: J5.23; also elsewhere on the board
GPIO12: J5.32, J17.3, J19.4; also elsewhere on the board
GPIO13: J5.33; also elsewhere on the board
GPIO14: J5.8, J5.10; also elsewhere on the board
GPIO16: J5.36, J17.6, J19.6; also elsewhere on the board
GPIO17: J5.11; also elsewhere on the board
GPIO18: J5.12; also elsewhere on the board
GPIO19: J5.35; also elsewhere on the board
GPIO20: J5.38, J17.4, J19.2; also elsewhere on the board
GPIO21: J5.40, J17.5, J19.8; also elsewhere on the board
GPIO22: J5.15; also elsewhere on the board
GPIO23: J5.16; also elsewhere on the board
GPIO24: J5.18; also elsewhere on the board
GPIO25: J5.22; also elsewhere on the board
GPIO26: J5.37; also elsewhere on the board
GPIO27: J5.13; also elsewhere on the board
ID_SC: J18.1, R15.2, U13.6 (SCL); also elsewhere on the board
ID_SD: J18.3, R16.2, U13.5 (SDA); also elsewhere on the board
unnamed: D1.4 (DIN), R23.1
unnamed: D1.2 (DOUT), D2.4 (DIN)
unnamed: D2.2 (DOUT), D3.4 (DIN)
unnamed: D3.2 (DOUT), D4.4 (DIN)
unnamed: D4.2 (DOUT), D5.4 (DIN)
unnamed: D5.2 (DOUT), D6.4 (DIN)
unnamed: D7.2 (A), R9.2
unnamed: D8.2 (A), R10.2
unnamed: D9.2 (A), R11.2
unnamed: D10.2 (A), R12.2
unnamed: F1.2, J12.4
unnamed: F2.2, J12.1
unnamed: J3.3 (TX_DISABLE), R17.1
unnamed: J4.3 (TX_DISABLE), R18.1
unnamed: C10.1, C11.1, J14.2, U14.3 (VO)
unnamed: R25.2, R26.2
unnamed: U11.3 (G), U11.8 (G)
unnamed: U12.3 (G), U12.8 (G)
OLED_BL: J3.2 (TX_FAULT), J11.8, R20.2; also elsewhere on the board
OLED_CLK: J11.3; also elsewhere on the board
OLED_CS: J3.8 (RX_LOS), J11.7, R19.2; also elsewhere on the board
OLED_DC: J11.6; also elsewhere on the board
OLED_MOSI: J11.4; also elsewhere on the board
OLED_RES: J11.5; also elsewhere on the board
RS0: J3.7 (RS0), J4.7 (RS0), R28.2; also elsewhere on the board
RS1: J3.9 (RS1), J4.9 (RS1), R29.2; also elsewhere on the board
SCL0: J3.5 (SCL), J4.5 (SCL), J5.28, J18.2, J20.2, R13.2; also elsewhere on the board
SDA0: J3.4 (SDA), J4.4 (SDA), J5.27, J18.4, J20.4, R14.2; also elsewhere on the board
SD_CLK: J7.5 (CLK); also elsewhere on the board
SD_CMD: J7.3 (CMD), R50.1; also elsewhere on the board
SD_DAT0: J7.7 (DAT0), R46.1; also elsewhere on the board
SD_DAT1: J7.8 (DAT1), R47.1; also elsewhere on the board
SD_DAT2: J7.1 (DAT2), R48.1; also elsewhere on the board
SD_DAT3: J7.2 (DAT3/CD), R49.1; also elsewhere on the board
SFP0_MOD_ABS: J3.6 (MOD_ABS), R27.2; also elsewhere on the board
SFP0_RX_N: J3.12 (RD-), R37.1, U9.5 (IO4)
SFP0_RX_P: J3.13 (RD+), R36.1, U9.4 (IO3)
SFP0_TX_N: J3.19 (TD-), R35.1, U9.1 (IO1)
SFP0_TX_P: J3.18 (TD+), R34.1, U9.2 (IO2)
SFP1_MOD_ABS: J4.6 (MOD_ABS), R24.2; also elsewhere on the board
SFP1_RX_N: J4.12 (RD-), R32.1, U10.5 (IO4)
SFP1_RX_P: J4.13 (RD+), R33.1, U10.4 (IO3)
SFP1_TX_N: J4.19 (TD-), R30.1, U10.1 (IO1)
SFP1_TX_P: J4.18 (TD+), R31.1, U10.2 (IO2)
SPDIF_IN: J9.3 (VIN); also elsewhere on the board
SPDIF_OUT: J10.1 (VOUT); also elsewhere on the board
USB_ID: J6.10; also elsewhere on the board
VCCR: C14.1, C15.1, FB2.1, J3.15 (VccR), J4.15 (VccR)
VCCT: C12.1, C13.1, FB1.2, J3.16 (VccT), J4.16 (VccT)

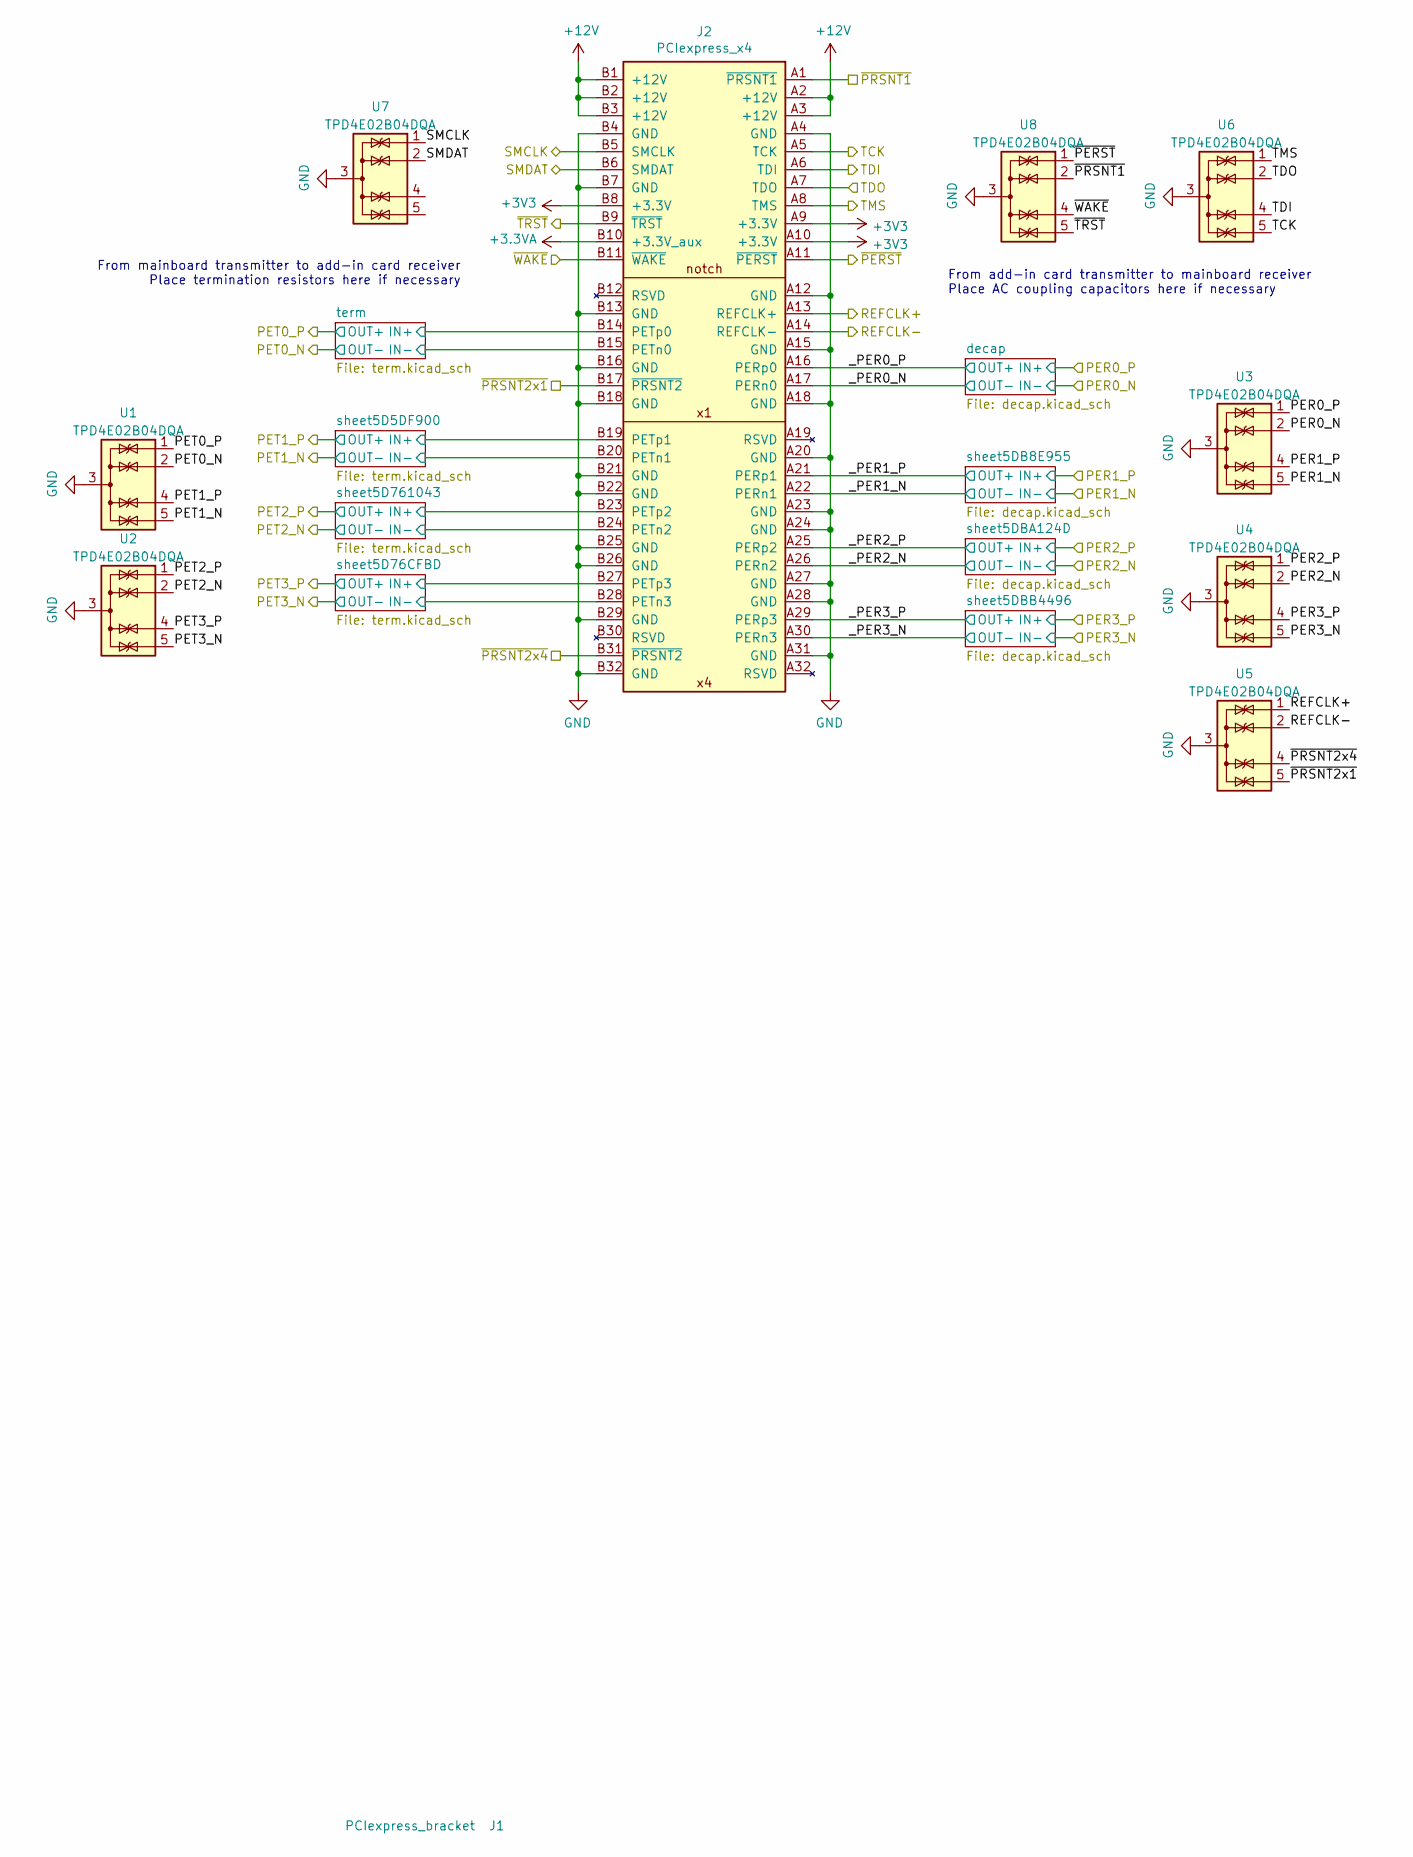
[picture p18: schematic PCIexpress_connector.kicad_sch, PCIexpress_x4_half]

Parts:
J1: PCIexpress_bracket; PCIexpress_bracket_full
J2: PCIexpress_x4
U1, U2, U3, U4, U5, U6, U7, U8: TPD4E02B04DQA; USON-10_2.5x1.0mm_P0.5mm

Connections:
+3.3VA: J2.B10 (+3.3V_aux); also elsewhere on the board
+3V3: J2.A9 (+3.3V), J2.A10 (+3.3V), J2.B8 (+3.3V)
+12V: J2.A2 (+12V), J2.A3 (+12V), J2.B1 (+12V), J2.B2 (+12V), J2.B3 (+12V); also elsewhere on the board
/PCIexpress_connector/_PER0_N: J2.A17 (PERn0); also elsewhere on the board
/PCIexpress_connector/_PER0_P: J2.A16 (PERp0); also elsewhere on the board
/PCIexpress_connector/_PER1_N: J2.A22 (PERn1); also elsewhere on the board
/PCIexpress_connector/_PER1_P: J2.A21 (PERp1); also elsewhere on the board
/PCIexpress_connector/_PER2_N: J2.A26 (PERn2); also elsewhere on the board
/PCIexpress_connector/_PER2_P: J2.A25 (PERp2); also elsewhere on the board
/PCIexpress_connector/_PER3_N: J2.A30 (PERn3); also elsewhere on the board
/PCIexpress_connector/_PER3_P: J2.A29 (PERp3); also elsewhere on the board
/PER0_N: U3.2 (IO2); also elsewhere on the board
/PER0_P: U3.1 (IO1); also elsewhere on the board
/PER1_N: U3.5 (IO4); also elsewhere on the board
/PER1_P: U3.4 (IO3); also elsewhere on the board
/PER2_PCIe_N: U4.2 (IO2); also elsewhere on the board
/PER2_PCIe_P: U4.1 (IO1); also elsewhere on the board
/PER3_PCIe_N: U4.5 (IO4); also elsewhere on the board
/PER3_PCIe_P: U4.4 (IO3); also elsewhere on the board
/PET0_N: J2.B15 (PETn0), U1.2 (IO2); also elsewhere on the board
/PET0_P: J2.B14 (PETp0), U1.1 (IO1); also elsewhere on the board
/PET1_N: J2.B20 (PETn1), U1.5 (IO4); also elsewhere on the board
/PET1_P: J2.B19 (PETp1), U1.4 (IO3); also elsewhere on the board
/PET2_PCIe_N: J2.B24 (PETn2), U2.2 (IO2); also elsewhere on the board
/PET2_PCIe_P: J2.B23 (PETp2), U2.1 (IO1); also elsewhere on the board
/PET3_PCIe_N: J2.B28 (PETn3), U2.5 (IO4); also elsewhere on the board
/PET3_PCIe_P: J2.B27 (PETp3), U2.4 (IO3); also elsewhere on the board
/REFCLK+: J2.A13 (REFCLK+), U5.1 (IO1); also elsewhere on the board
/REFCLK-: J2.A14 (REFCLK-), U5.2 (IO2); also elsewhere on the board
/SMCLK: J2.B5 (SMCLK), U7.1 (IO1); also elsewhere on the board
/SMDAT: J2.B6 (SMDAT), U7.2 (IO2); also elsewhere on the board
/TCK: J2.A5 (TCK), U6.5 (IO4); also elsewhere on the board
/TDI: J2.A6 (TDI), U6.4 (IO3); also elsewhere on the board
/TDO: J2.A7 (TDO), U6.2 (IO2); also elsewhere on the board
/TMS: J2.A8 (TMS), U6.1 (IO1); also elsewhere on the board
/~PERST: J2.A11 (~PERST), U8.1 (IO1); also elsewhere on the board
/~PRSNT1: J2.A1 (~PRSNT1), U8.2 (IO2); also elsewhere on the board
/~PRSNT2x1: J2.B17 (~PRSNT2), U5.5 (IO4); also elsewhere on the board
/~PRSNT2x4: J2.B31 (~PRSNT2), U5.4 (IO3); also elsewhere on the board
/~TRST: J2.B9 (~TRST), U8.5 (IO4)
/~WAKE: J2.B11 (~WAKE), U8.4 (IO3); also elsewhere on the board
GND: J2.A4 (GND), J2.A12 (GND), J2.A15 (GND), J2.A18 (GND), J2.A20 (GND), J2.A23 (GND), J2.A24 (GND), J2.A27 (GND), J2.A28 (GND), J2.A31 (GND), J2.B4 (GND), J2.B7 (GND), J2.B13 (GND), J2.B16 (GND), J2.B18 (GND), J2.B21 (GND), J2.B22 (GND), J2.B25 (GND), J2.B26 (GND), J2.B29 (GND), J2.B32 (GND), U1.3 (G), U1.8 (G), U2.3 (G), U2.8 (G), U3.3 (G), U3.8 (G), U4.3 (G), U4.8 (G), U5.3 (G), U5.8 (G), U6.3 (G), U6.8 (G), U7.3 (G), U7.8 (G), U8.3 (G), U8.8 (G); also elsewhere on the board

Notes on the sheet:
From mainboard transmitter to add-in card receiver Place termination resistors here if necessary
From add-in card transmitter to mainboard receiver Place AC coupling capacitors here if necessary

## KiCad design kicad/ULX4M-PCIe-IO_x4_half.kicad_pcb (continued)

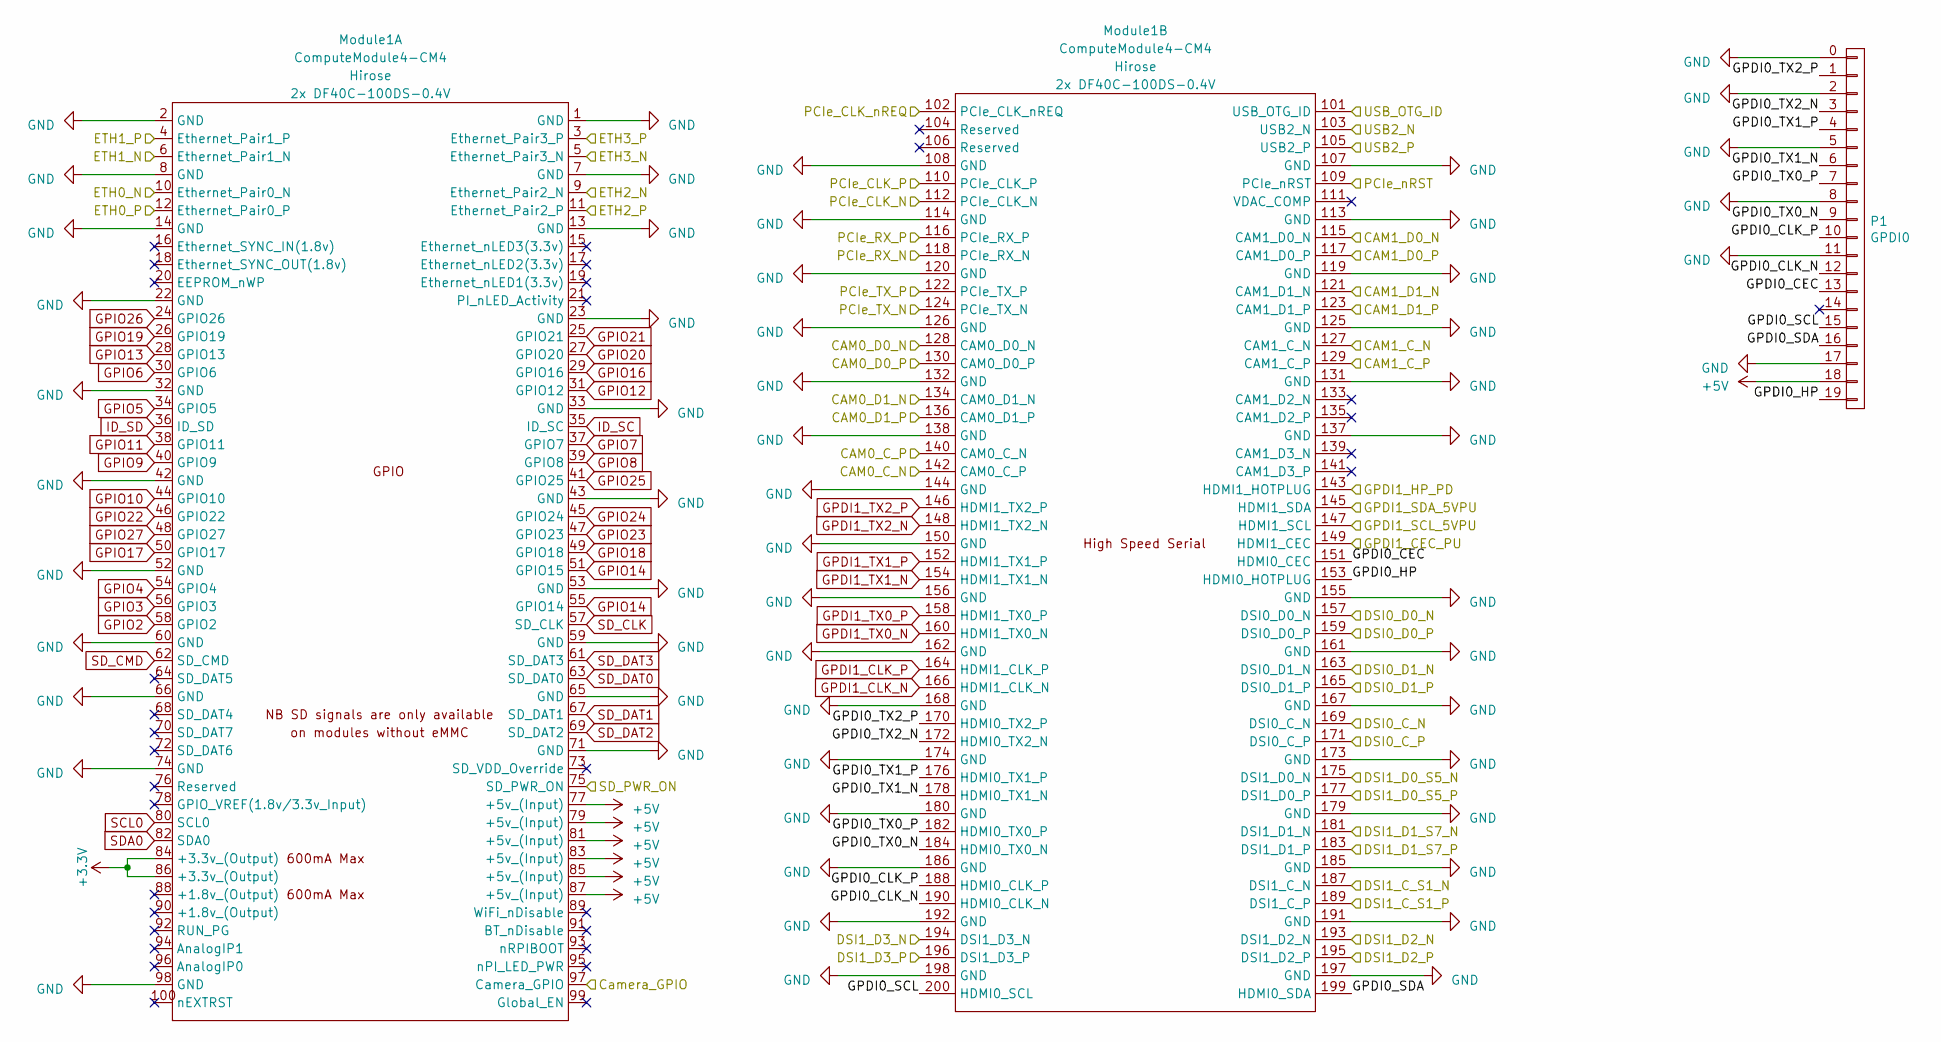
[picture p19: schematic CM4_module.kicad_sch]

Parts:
Module1: ComputeModule4-CM4; Raspberry-Pi-4-Compute-Module
P1: GPDI0; CONN-10029449-111RLF

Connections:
+3.3V: Module1.84 (+3.3v_(Output)), Module1.86 (+3.3v_(Output)); also elsewhere on the board
+5V: Module1.77 (+5v_(Input)), Module1.79 (+5v_(Input)), Module1.81 (+5v_(Input)), Module1.83 (+5v_(Input)), Module1.85 (+5v_(Input)), Module1.87 (+5v_(Input)), P1.18; also elsewhere on the board
/CAM0_D0_N: Module1.128 (CAM0_D0_N); also elsewhere on the board
/CAM0_D0_P: Module1.130 (CAM0_D0_P); also elsewhere on the board
/CAM0_D1_N: Module1.134 (CAM0_D1_N); also elsewhere on the board
/CAM0_D1_P: Module1.136 (CAM0_D1_P); also elsewhere on the board
/CAM1_D0_N: Module1.115 (CAM1_D0_N); also elsewhere on the board
/CAM1_D0_P: Module1.117 (CAM1_D0_P); also elsewhere on the board
/CAM1_D1_N: Module1.121 (CAM1_D1_N); also elsewhere on the board
/CAM1_D1_P: Module1.123 (CAM1_D1_P); also elsewhere on the board
/CM4_module/DSI1_D2_P: Module1.195 (DSI1_D2_P)
/CM4_module/GPDI0_CEC: Module1.151 (HDMI0_CEC), P1.13
/CM4_module/GPDI0_CLK_N: Module1.190 (HDMI0_CLK_N), P1.12
/CM4_module/GPDI0_CLK_P: Module1.188 (HDMI0_CLK_P), P1.10
/CM4_module/GPDI0_HP: Module1.153 (HDMI0_HOTPLUG), P1.19
/CM4_module/GPDI0_SCL: Module1.200 (HDMI0_SCL), P1.15
/CM4_module/GPDI0_SDA: Module1.199 (HDMI0_SDA), P1.16
/CM4_module/GPDI0_TX0_N: Module1.184 (HDMI0_TX0_N), P1.9
/CM4_module/GPDI0_TX0_P: Module1.182 (HDMI0_TX0_P), P1.7
/CM4_module/GPDI0_TX1_N: Module1.178 (HDMI0_TX1_N), P1.6
/CM4_module/GPDI0_TX1_P: Module1.176 (HDMI0_TX1_P), P1.4
/CM4_module/GPDI0_TX2_N: Module1.172 (HDMI0_TX2_N), P1.3
/CM4_module/GPDI0_TX2_P: Module1.170 (HDMI0_TX2_P), P1.1
/EXT_CLK_REF1_N: Module1.142 (CAM0_C_P); also elsewhere on the board
/EXT_CLK_REF1_P: Module1.140 (CAM0_C_N); also elsewhere on the board
/EXT_CLK_REF2_N: Module1.127 (CAM1_C_N); also elsewhere on the board
/EXT_CLK_REF2_P: Module1.129 (CAM1_C_P); also elsewhere on the board
/EXT__SER_CLK_REF_N: Module1.187 (DSI1_C_N); also elsewhere on the board
/EXT__SER_CLK_REF_P: Module1.189 (DSI1_C_P); also elsewhere on the board
/PER0_N: Module1.118 (PCIe_RX_N); also elsewhere on the board
/PER0_P: Module1.116 (PCIe_RX_P); also elsewhere on the board
/PER1_N: Module1.5 (Ethernet_Pair3_N); also elsewhere on the board
/PER1_P: Module1.3 (Ethernet_Pair3_P); also elsewhere on the board
/PER2_N: Module1.10 (Ethernet_Pair0_N); also elsewhere on the board
/PER2_P: Module1.12 (Ethernet_Pair0_P); also elsewhere on the board
/PER3_N: Module1.175 (DSI1_D0_N); also elsewhere on the board
/PER3_P: Module1.177 (DSI1_D0_P); also elsewhere on the board
/PET0_N: Module1.124 (PCIe_TX_N); also elsewhere on the board
/PET0_P: Module1.122 (PCIe_TX_P); also elsewhere on the board
/PET1_N: Module1.9 (Ethernet_Pair2_N); also elsewhere on the board
/PET1_P: Module1.11 (Ethernet_Pair2_P); also elsewhere on the board
/PET2_N: Module1.6 (Ethernet_Pair1_N); also elsewhere on the board
/PET2_P: Module1.4 (Ethernet_Pair1_P); also elsewhere on the board
/PET3_N: Module1.181 (DSI1_D1_N); also elsewhere on the board
/PET3_P: Module1.183 (DSI1_D1_P); also elsewhere on the board
/REFCLK+: Module1.110 (PCIe_CLK_P); also elsewhere on the board
/REFCLK-: Module1.112 (PCIe_CLK_N); also elsewhere on the board
/RGB_DATA: Module1.194 (DSI1_D3_N); also elsewhere on the board
/RX_LOS_1: Module1.159 (DSI0_D0_P); also elsewhere on the board
/TX_FAULT_1: Module1.157 (DSI0_D0_N); also elsewhere on the board
/~PERST: Module1.109 (PCIe_nRST); also elsewhere on the board
/~WAKE: Module1.102 (PCIe_CLK_nREQ); also elsewhere on the board
D+: Module1.105 (USB2_P); also elsewhere on the board
D-: Module1.103 (USB2_N); also elsewhere on the board
GND: Module1.1 (GND), Module1.2 (GND), Module1.7 (GND), Module1.8 (GND), Module1.13 (GND), Module1.14 (GND), Module1.22 (GND), Module1.23 (GND), Module1.32 (GND), Module1.33 (GND), Module1.42 (GND), Module1.43 (GND), Module1.52 (GND), Module1.53 (GND), Module1.59 (GND), Module1.60 (GND), Module1.65 (GND), Module1.66 (GND), Module1.71 (GND), Module1.74 (GND), Module1.98 (GND), Module1.107 (GND), Module1.108 (GND), Module1.113 (GND), Module1.114 (GND), Module1.119 (GND), Module1.120 (GND), Module1.125 (GND), Module1.126 (GND), Module1.131 (GND), Module1.132 (GND), Module1.137 (GND), Module1.138 (GND), Module1.144 (GND), Module1.150 (GND), Module1.155 (GND), Module1.156 (GND), Module1.161 (GND), Module1.162 (GND), Module1.167 (GND), Module1.168 (GND), Module1.173 (GND), Module1.174 (GND), Module1.179 (GND), Module1.180 (GND), Module1.185 (GND), Module1.186 (GND), Module1.191 (GND), Module1.192 (GND), Module1.197 (GND), Module1.198 (GND), P1.0, P1.2, P1.5, P1.8, P1.11, P1.17; also elsewhere on the board
GPDI1_CLK_N: Module1.166 (HDMI1_CLK_N); also elsewhere on the board
GPDI1_CLK_P: Module1.164 (HDMI1_CLK_P); also elsewhere on the board
GPDI1_TX0_N: Module1.160 (HDMI1_TX0_N); also elsewhere on the board
GPDI1_TX0_P: Module1.158 (HDMI1_TX0_P); also elsewhere on the board
GPDI1_TX1_N: Module1.154 (HDMI1_TX1_N); also elsewhere on the board
GPDI1_TX1_P: Module1.152 (HDMI1_TX1_P); also elsewhere on the board
GPDI1_TX2_N: Module1.148 (HDMI1_TX2_N); also elsewhere on the board
GPDI1_TX2_P: Module1.146 (HDMI1_TX2_P); also elsewhere on the board
GPIO2: Module1.58 (GPIO2); also elsewhere on the board
GPIO3: Module1.56 (GPIO3); also elsewhere on the board
GPIO4: Module1.54 (GPIO4); also elsewhere on the board
GPIO5: Module1.34 (GPIO5); also elsewhere on the board
GPIO6: Module1.30 (GPIO6); also elsewhere on the board
GPIO7: Module1.37 (GPIO7); also elsewhere on the board
GPIO8: Module1.39 (GPIO8); also elsewhere on the board
GPIO9: Module1.40 (GPIO9); also elsewhere on the board
GPIO10: Module1.44 (GPIO10); also elsewhere on the board
GPIO11: Module1.38 (GPIO11); also elsewhere on the board
GPIO12: Module1.31 (GPIO12); also elsewhere on the board
GPIO13: Module1.28 (GPIO13); also elsewhere on the board
GPIO14: Module1.51 (GPIO15), Module1.55 (GPIO14); also elsewhere on the board
GPIO16: Module1.29 (GPIO16); also elsewhere on the board
GPIO17: Module1.50 (GPIO17); also elsewhere on the board
GPIO18: Module1.49 (GPIO18); also elsewhere on the board
GPIO19: Module1.26 (GPIO19); also elsewhere on the board
GPIO20: Module1.27 (GPIO20); also elsewhere on the board
GPIO21: Module1.25 (GPIO21); also elsewhere on the board
GPIO22: Module1.46 (GPIO22); also elsewhere on the board
GPIO23: Module1.47 (GPIO23); also elsewhere on the board
GPIO24: Module1.45 (GPIO24); also elsewhere on the board
GPIO25: Module1.41 (GPIO25); also elsewhere on the board
GPIO26: Module1.24 (GPIO26); also elsewhere on the board
GPIO27: Module1.48 (GPIO27); also elsewhere on the board
ID_SC: Module1.35 (ID_SC); also elsewhere on the board
ID_SD: Module1.36 (ID_SD); also elsewhere on the board
OLED_BL: Module1.97 (Camera_GPIO); also elsewhere on the board
OLED_CLK: Module1.147 (HDMI1_SCL); also elsewhere on the board
OLED_CS: Module1.75 (SD_PWR_ON); also elsewhere on the board
OLED_DC: Module1.149 (HDMI1_CEC); also elsewhere on the board
OLED_MOSI: Module1.145 (HDMI1_SDA); also elsewhere on the board
OLED_RES: Module1.143 (HDMI1_HOTPLUG); also elsewhere on the board
RS0: Module1.165 (DSI0_D1_P); also elsewhere on the board
RS1: Module1.163 (DSI0_D1_N); also elsewhere on the board
SCL0: Module1.80 (SCL0); also elsewhere on the board
SDA0: Module1.82 (SDA0); also elsewhere on the board
SD_CLK: Module1.57 (SD_CLK); also elsewhere on the board
SD_CMD: Module1.62 (SD_CMD); also elsewhere on the board
SD_DAT0: Module1.63 (SD_DAT0); also elsewhere on the board
SD_DAT1: Module1.67 (SD_DAT1); also elsewhere on the board
SD_DAT2: Module1.69 (SD_DAT2); also elsewhere on the board
SD_DAT3: Module1.61 (SD_DAT3); also elsewhere on the board
SFP0_MOD_ABS: Module1.193 (DSI1_D2_N); also elsewhere on the board
SFP1_MOD_ABS: Module1.196 (DSI1_D3_P); also elsewhere on the board
SPDIF_IN: Module1.171 (DSI0_C_P); also elsewhere on the board
SPDIF_OUT: Module1.169 (DSI0_C_N); also elsewhere on the board
USB_ID: Module1.101 (USB_OTG_ID); also elsewhere on the board

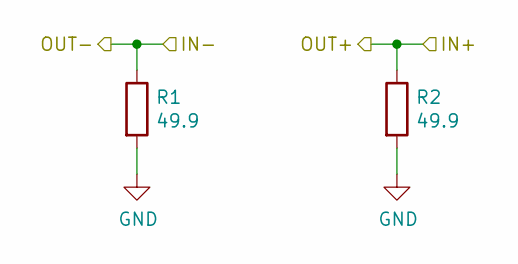
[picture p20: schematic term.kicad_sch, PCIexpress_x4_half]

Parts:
R1, R2: 49.9; R_0603_1608Metric

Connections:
/PET0_N: R1.1; also elsewhere on the board
/PET0_P: R2.1; also elsewhere on the board
GND: R1.2, R2.2; also elsewhere on the board

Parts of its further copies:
R3, R4, R5, R6, R7, R8: 49.9; R_0603_1608Metric

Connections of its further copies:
/PET1_N: R3.1; also elsewhere on the board
/PET1_P: R4.1; also elsewhere on the board
/PET2_PCIe_N: R5.1; also elsewhere on the board
/PET2_PCIe_P: R6.1; also elsewhere on the board
/PET3_PCIe_N: R7.1; also elsewhere on the board
/PET3_PCIe_P: R8.1; also elsewhere on the board
GND: R3.2, R4.2, R5.2, R6.2, R7.2, R8.2; also elsewhere on the board

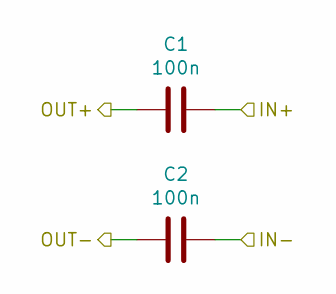
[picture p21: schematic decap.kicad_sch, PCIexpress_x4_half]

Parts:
C1, C2: 100n; C_0603_1608Metric

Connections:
/PCIexpress_connector/_PER0_N: C2.1; also elsewhere on the board
/PCIexpress_connector/_PER0_P: C1.2; also elsewhere on the board
/PER0_N: C2.2; also elsewhere on the board
/PER0_P: C1.1; also elsewhere on the board

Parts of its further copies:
C3, C4, C5, C6, C7, C8: 100n; C_0603_1608Metric

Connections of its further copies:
/PCIexpress_connector/_PER1_N: C4.1; also elsewhere on the board
/PCIexpress_connector/_PER1_P: C3.2; also elsewhere on the board
/PCIexpress_connector/_PER2_N: C6.1; also elsewhere on the board
/PCIexpress_connector/_PER2_P: C5.2; also elsewhere on the board
/PCIexpress_connector/_PER3_N: C8.1; also elsewhere on the board
/PCIexpress_connector/_PER3_P: C7.2; also elsewhere on the board
/PER1_N: C4.2; also elsewhere on the board
/PER1_P: C3.1; also elsewhere on the board
/PER2_PCIe_N: C6.2; also elsewhere on the board
/PER2_PCIe_P: C5.1; also elsewhere on the board
/PER3_PCIe_N: C8.2; also elsewhere on the board
/PER3_PCIe_P: C7.1; also elsewhere on the board

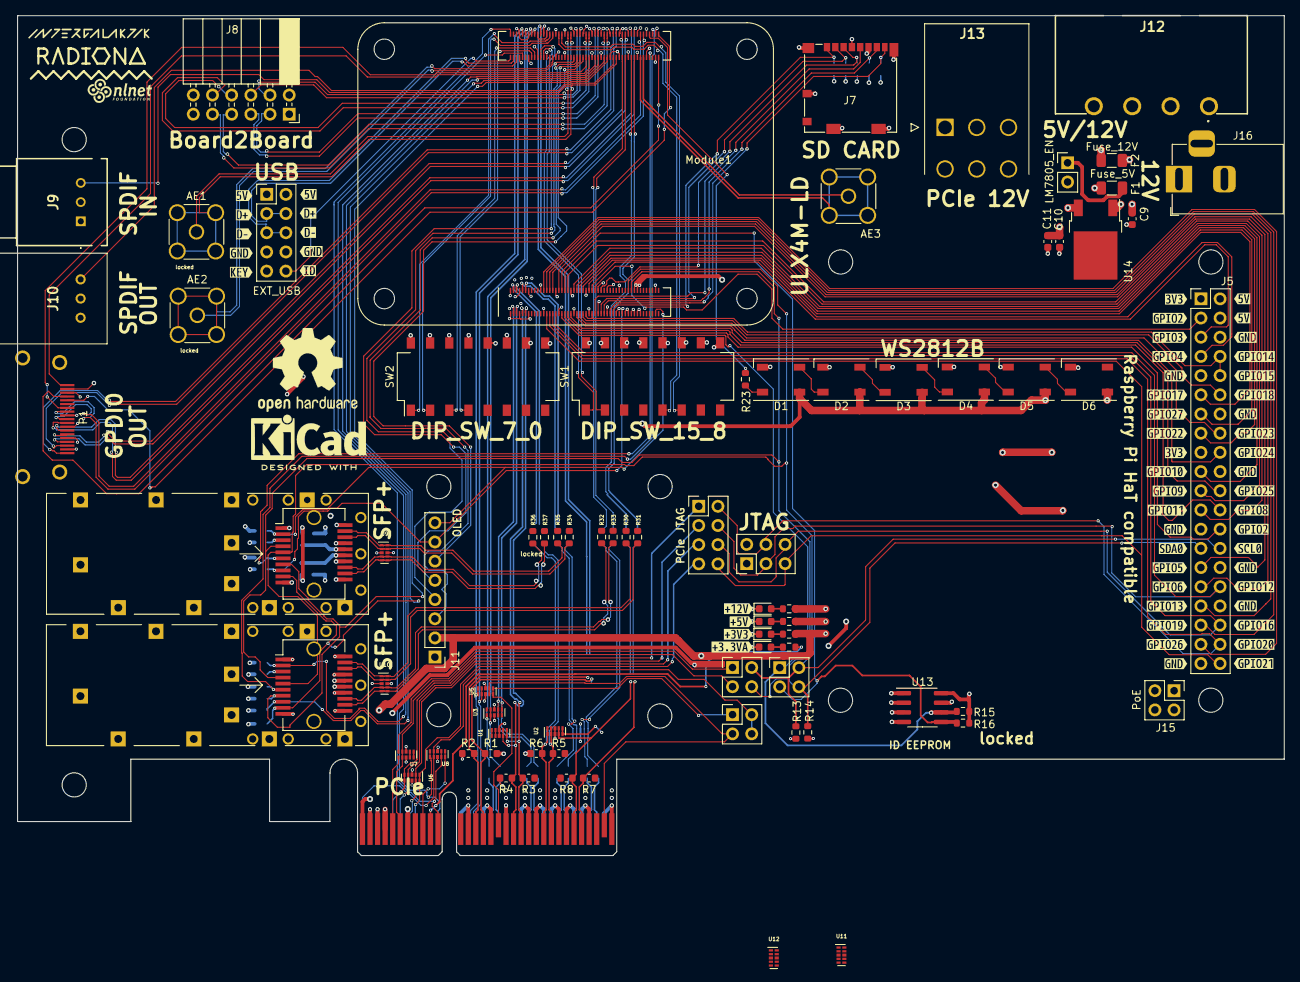
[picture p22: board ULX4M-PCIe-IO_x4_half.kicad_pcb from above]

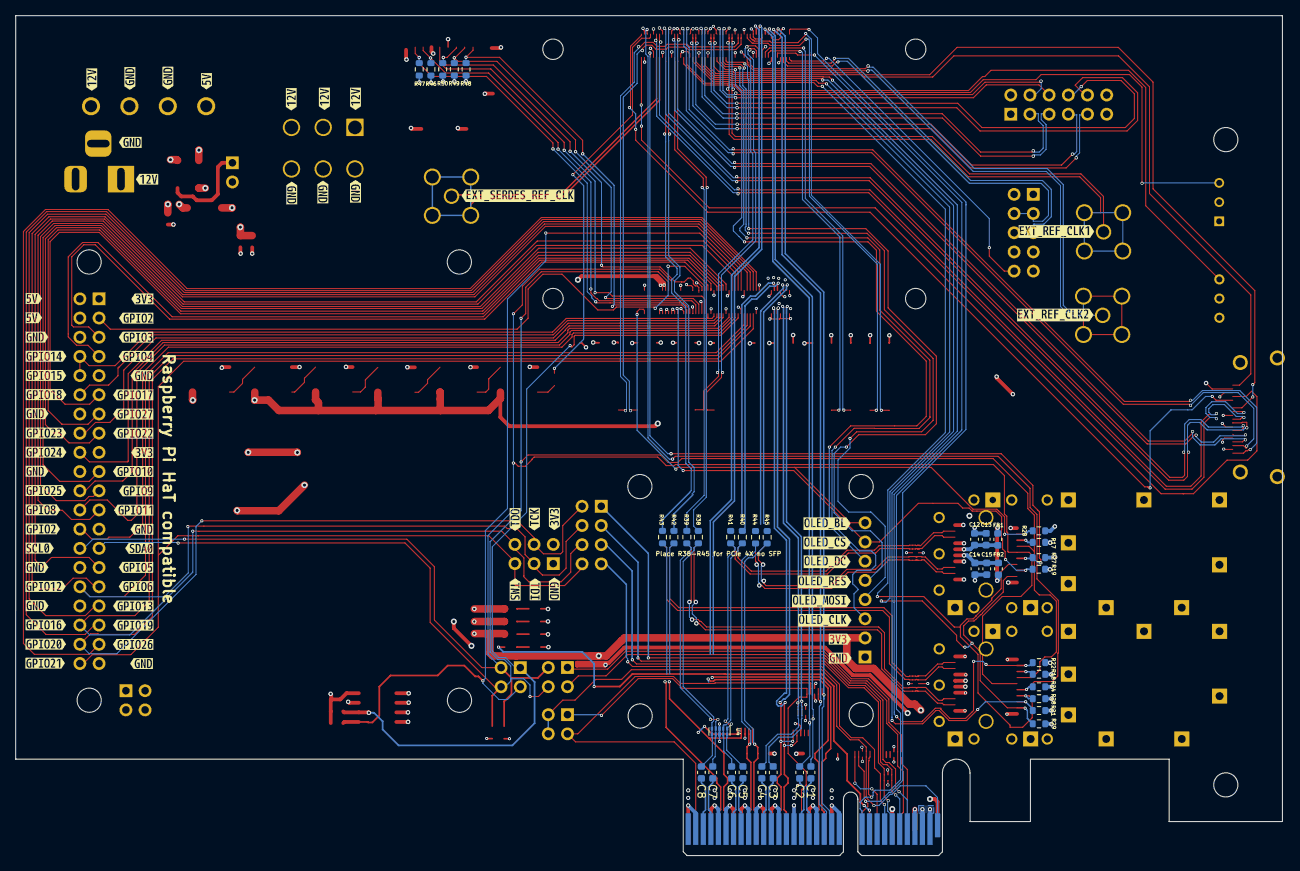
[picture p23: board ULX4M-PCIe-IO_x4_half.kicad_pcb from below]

Board: 4 copper layers, 167.7 x 111.2 mm, 251 parts (107 on the bottom side), 164 nets.

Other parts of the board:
kibuzzard-63524D1: G***; kibuzzard-63524D95
kibuzzard-63524E7F12: G***; kibuzzard-63524E7F
kibuzzard-63524EC5: G***; kibuzzard-63524EC5
kibuzzard-63524ECE: G***; kibuzzard-63524ECE
kibuzzard-63524ED4: G***; kibuzzard-63524ED4
kibuzzard-63524EDC: G***; kibuzzard-63524EDC
kibuzzard-63524EE2: G***; kibuzzard-63524EE2
kibuzzard-63524EEA: G***; kibuzzard-63524EEA
kibuzzard-63524EF7: G***; kibuzzard-63524EF7
kibuzzard-63524EFF: G***; kibuzzard-63524EFF
kibuzzard-63524F4A: G***; kibuzzard-63524F4A
kibuzzard-63524F4F: G***; kibuzzard-63524F4F
kibuzzard-63524F5B: G***; kibuzzard-63524F5B
kibuzzard-63524F6E: G***; kibuzzard-63524F6E
kibuzzard-63524F8C: G***; kibuzzard-63524F8C
kibuzzard-63524F9F: G***; kibuzzard-63524F9F
kibuzzard-63524F11: G***; kibuzzard-63524F11
kibuzzard-63524F17: G***; kibuzzard-63524F17
kibuzzard-63524F21: G***; kibuzzard-63524F21
kibuzzard-63524F28: G***; kibuzzard-63524F28
kibuzzard-63524F31: G***; kibuzzard-63524F31
kibuzzard-63524F38: G***; kibuzzard-63524F38
kibuzzard-63524F40: G***; kibuzzard-63524F40
kibuzzard-63524F45: G***; kibuzzard-63524F45
kibuzzard-63524F57: G***; kibuzzard-63524F57
kibuzzard-63524F60: G***; kibuzzard-63524F60
kibuzzard-63524F75: G***; kibuzzard-63524F75
kibuzzard-63524F84: G***; kibuzzard-63524F84
kibuzzard-63524F92: G***; kibuzzard-63524F92
kibuzzard-63524F99: G***; kibuzzard-63524F99
kibuzzard-63524FA8: G***; kibuzzard-63524FA8
kibuzzard-63524FAF: G***; kibuzzard-63524FAF
kibuzzard-63524FB4: G***; kibuzzard-63524FB4
kibuzzard-63524FBB: G***; kibuzzard-63524FBB
kibuzzard-63524FC2: G***; kibuzzard-63524FC2
kibuzzard-63524FC9: G***; kibuzzard-63524FC9
kibuzzard-63524FCF: G***; kibuzzard-63524FCF
kibuzzard-63524FD4: G***; kibuzzard-63524FD4
kibuzzard-63524FDC: G***; kibuzzard-63524FDC
kibuzzard-63524FE4: G***; kibuzzard-63524FE4
kibuzzard-63525A7A: G***; kibuzzard-63525A7A
kibuzzard-63525A8D: G***; kibuzzard-63525A8D
kibuzzard-63525A73: G***; kibuzzard-63525A73
kibuzzard-63525A80: G***; kibuzzard-63525A80
kibuzzard-63525A86: G***; kibuzzard-63525A86
kibuzzard-63525A94: G***; kibuzzard-63525A94
kibuzzard-63525AA1: G***; kibuzzard-63525AA1
kibuzzard-63525AA7: G***; kibuzzard-63525AA7
kibuzzard-63525B68: G***; kibuzzard-63525B68
kibuzzard-63525B89: G***; kibuzzard-63525B89
kibuzzard-63525BEB: G***; kibuzzard-63525BEB
kibuzzard-63525C1D: G***; kibuzzard-63525C1D
kibuzzard-63525C11: G***; kibuzzard-63525C11
kibuzzard-63525C35: G***; kibuzzard-63525C35
kibuzzard-63525FEA: G***; kibuzzard-63525FEA
kibuzzard-635253B6: G***; kibuzzard-635253B6
kibuzzard-635253BD: G***; kibuzzard-635253BD
kibuzzard-635253C7: G***; kibuzzard-635253C7
kibuzzard-635253DB: G***; kibuzzard-635253DB
kibuzzard-635253E6: G***; kibuzzard-635253E6
kibuzzard-635253EF: G***; kibuzzard-635253EF
kibuzzard-635253F9: G***; kibuzzard-635253F9
kibuzzard-635254E9: G***; kibuzzard-635254E9
kibuzzard-635254FF: G***; kibuzzard-635254FF
kibuzzard-635255A4: G***; kibuzzard-635255A4
kibuzzard-635255AB: G***; kibuzzard-635255AB
kibuzzard-635256A7: G***; kibuzzard-635256A7
kibuzzard-635256BE: G***; kibuzzard-635256BE
kibuzzard-635256C7: G***; kibuzzard-635256C7
kibuzzard-635256D0: G***; kibuzzard-635256D0
kibuzzard-635256DB: G***; kibuzzard-635256DB
kibuzzard-635669BB: G***; kibuzzard-635669BB
kibuzzard-6352538D: G***; kibuzzard-6352538D
kibuzzard-6352539E: G***; kibuzzard-6352539E
kibuzzard-6352540A: G***; kibuzzard-6352540A
kibuzzard-6352542E: G***; kibuzzard-6352542E
kibuzzard-6352550F: G***; kibuzzard-6352550F
kibuzzard-6352551E: G***; kibuzzard-6352551E
kibuzzard-6352553D: G***; kibuzzard-6352553D
kibuzzard-6352554A: G***; kibuzzard-6352554A
kibuzzard-6352557B: G***; kibuzzard-6352557B
kibuzzard-6352559E: G***; kibuzzard-6352559E
kibuzzard-6352571C, kibuzzard-6352571C#2, kibuzzard-6352571C#3, kibuzzard-6352571C#4, kibuzzard-6352571C#5, kibuzzard-6352571C#6: G***; kibuzzard-6352571C
kibuzzard-6352575D: G***; kibuzzard-6352575D
kibuzzard-6352604E: G***; kibuzzard-6352604E
kibuzzard-6352607D: G***; kibuzzard-6352607D
kibuzzard-6352608E: G***; kibuzzard-6352608E
kibuzzard-6352880A: G***; kibuzzard-6352880A
kibuzzard-63525329: G***; kibuzzard-63525329
kibuzzard-63525356: G***; kibuzzard-63525356
kibuzzard-63525372: G***; kibuzzard-63525372
kibuzzard-63525383: G***; kibuzzard-63525383
kibuzzard-63525395: G***; kibuzzard-63525395
kibuzzard-63525401: G***; kibuzzard-63525401
kibuzzard-63525414: G***; kibuzzard-63525414
kibuzzard-63525426: G***; kibuzzard-63525426
kibuzzard-63525437, kibuzzard-63525437#2: G***; kibuzzard-63525437
kibuzzard-63525509: G***; kibuzzard-63525509
kibuzzard-63525515: G***; kibuzzard-63525515
kibuzzard-63525524: G***; kibuzzard-63525524
kibuzzard-63525536: G***; kibuzzard-63525536
kibuzzard-63525544: G***; kibuzzard-63525544
kibuzzard-63525576: G***; kibuzzard-63525576
kibuzzard-63525581: G***; kibuzzard-63525581
kibuzzard-63525588: G***; kibuzzard-63525588
kibuzzard-63525590: G***; kibuzzard-63525590
kibuzzard-63525598: G***; kibuzzard-63525598
kibuzzard-63525733, kibuzzard-63525733#2, kibuzzard-63525733#3, kibuzzard-63525733#4, kibuzzard-63525733#5: G***; kibuzzard-63525733
kibuzzard-63526015: G***; kibuzzard-63526015
kibuzzard-63526058: G***; kibuzzard-63526058
kibuzzard-63526060: G***; kibuzzard-63526060
kibuzzard-63526086: G***; kibuzzard-63526086
kibuzzard-63526396: G***; kibuzzard-63526396
radiona: radiona

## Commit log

2022-10-12 Renaming all files fix #7
    [PCIexpress_connector.kicad_sch, PCIexpress_x4_half.kicad_pcb, ULX4M-PCIe-IO_x4_half.kicad_pcb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]
2022-10-12 Modules update
    [CM4_module.kicad_sch, ULX4M-PCIe-IO_x4_half.kicad_pcb, ULX4M-PCIe-IO_x4_half.kicad_sch]
2022-10-12 Schematics change
    [CM4_module.kicad_sch]
2022-10-12 Moving symbol and footprint to lib folder
2022-10-12 Adding SPDIF
    [CM4_module.kicad_sch, ULX4M-PCIe-IO_x4_half.kicad_pcb, ULX4M-PCIe-IO_x4_half.kicad_sch]
2022-10-12 Update connector
2022-10-13 Adding picture and reference boards
    [ULX4M-PCIe-IO_x4_half.kicad_pcb]
2022-10-15 Adding PCIe power connector - fix 31
    [PCIexpress_connector.kicad_sch, ULX4M-PCIe-IO_x4_half.kicad_pcb, ULX4M-PCIe-IO_x4_half.kicad_sch]
2022-10-15 Adding logos and version text fix #3 fix #24
    [ULX4M-PCIe-IO_x4_half.kicad_pcb]
2022-10-15 Adding LEDs fix #4
    [ULX4M-PCIe-IO_x4_half.kicad_pcb, ULX4M-PCIe-IO_x4_half.kicad_sch]
2022-10-20 Adding more features
    [PCIexpress_connector.kicad_sch, ULX4M-PCIe-IO_x4_half.kicad_pcb, ULX4M-PCIe-IO_x4_half.kicad_sch]
2022-10-20 Adding new 3D kicad render
    [ULX4M-PCIe-IO_x4_half.kicad_pcb]
2022-10-20 Adding barrel connector, adding JTAG, adding new pic
    [ULX4M-PCIe-IO_x4_half.kicad_pcb, ULX4M-PCIe-IO_x4_half.kicad_sch]
2022-10-20 Connecting GPIO, GPDI, B2B, SD
    [CM4_module.kicad_sch, ULX4M-PCIe-IO_x4_half.kicad_pcb, ULX4M-PCIe-IO_x4_half.kicad_sch]
2022-10-20 Adding more connections - adding SFP parts
    [ULX4M-PCIe-IO_x4_half.kicad_pcb, ULX4M-PCIe-IO_x4_half.kicad_sch]
2022-10-21 Adding more descrition to PCB pins
    [ULX4M-PCIe-IO_x4_half.kicad_pcb]
2022-10-24 finalising connections
    [CM4_module.kicad_sch, PCIexpress_connector.kicad_sch, ULX4M-PCIe-IO_x4_half.kicad_sch]
2022-10-24 Routing PCIe
    [CM4_module.kicad_sch, PCIexpress_connector.kicad_sch, ULX4M-PCIe-IO_x4_half.kicad_sch]
2022-10-25 Routing GPIOs
    [ULX4M-PCIe-IO_x4_half.kicad_pcb, ULX4M-PCIe-IO_x4_half.kicad_sch]
2022-10-25 Routing B2B
    [ULX4M-PCIe-IO_x4_half.kicad_pcb]
2022-10-26 Routing all pins from CM4 connector
    [ULX4M-PCIe-IO_x4_half.kicad_pcb]
2022-10-27 Routing all gpio
    [ULX4M-PCIe-IO_x4_half.kicad_sch]
2022-10-28 Adding blender render image
    [ULX4M-PCIe-IO_x4_half.kicad_pcb]
2024-08-21 Fixing errors - adding length match
    [ULX4M-PCIe-IO_x4_half-B_Cu.gbl, ULX4M-PCIe-IO_x4_half-B_Mask.gbs, ULX4M-PCIe-IO_x4_half-B_Paste.gbp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]
2025-04-10 uređena schema
    [CM4_module.kicad_sch, PCIexpress_connector.kicad_sch, ULX4M-PCIe-IO_x4_half.kicad_sch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]
2026-10-30 routing - CAM0 to connector
